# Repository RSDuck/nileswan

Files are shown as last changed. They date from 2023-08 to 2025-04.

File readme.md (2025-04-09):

# nileswan

An attempt at creating flash cartridge for Wonderswan.

Expect exciting things here.

## Building instructions

### Requirements

- [OSS CAD Suite](https://github.com/YosysHQ/oss-cad-suite-build) (FPGA core)
  - Requires a modified version of `icepack`, see below for more information
- [Wonderful Toolchain](https://wonderful.asie.pl/wiki/doku.php?id=getting_started) (IPL1, recovery, updater)
- CMake (MCU firmware)
- NASM (IPL0)
- Nim 2.0+ (FPGA core, IPL0)
- Ninja (MCU firmware)
- Python 3.x (SPI images, updater)
  - + `crc` library
- dd, dosfstools, mtools (emulator images)

#### icepack

For the FPGA to be ready in time, the bitstream needs to be loaded at the highest speed possible. I created a [PR](https://github.com/YosysHQ/icestorm/pull/332) for icepack which adds a setting to change this. Without it is not possible to compile the FPGA bitstream.

### Compiling

1. Make sure to fetch the Git submodules: `git submodule update --init --recursive`.
2. Run `make help` to read what build options are possible.
3. Run `make` (or `make ...`) to build the requested components.

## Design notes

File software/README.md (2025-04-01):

# software

Console-side software used by the nileswan's boot/manufacturing process.

## ipl0

The first stage bootloader; up to 512 bytes, stored in FPGA memory. Its goal is to:

- preserve initial boot state in console RAM for the second stage bootloader,
- choose the second stage bootloader to load (boot, safe),
- load the second stage bootloader from SPI flash to console RAM,
- jump to the second stage bootloader.

## ipl1

The second stage bootloader; up to ~15 kilobytes, stored in SPI flash. It contains
a few sub-variants:

### boot

This is the default second stage bootloader. Its goal is to:

- initialize the IPC memory layout,
- initialize the storage card inserted into the console,
- load a program (`/NILESWAN/MENU.WS`) to PSRAM,
- jump to PSRAM.

### safe

Its goal is to provide recovery options in case the user requests them by holding
the on-cartridge button at boot. This is still being worked on.

## libnile

Common library for nileswan functionality, developed in a separate repository.

## userland

Cartridge-layout programs using shared minimal user interface code.

### recovery

Larger recovery program which can optionally be launched through `ipl1/safe`.

### updater

This is the firmware updater program source code. It can be combined with a
manifest file to create an on-console flashable firmware upgrade.

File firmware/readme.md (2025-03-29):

# μController firmware

Firmware for the STM32L052K(6/8)Ux MCU. Its responsibilities include:

- USB communication (CDC, ...),
- real-time clock (time keeping, S-3511A emulation),
- backup EEPROM storage.

For RTC support/EEPROM storage, it is constantly powered by the backup battery, even when the console is powered off.

## Protocol

The MCU is connected on the same SPI bus as the SPI flash.

### Command mode

To initiate a transaction, send two bytes declaring the command ID (bits 0-6) and parameter (bits 7-15, values 0-511).

Each packet, except "Switch to mode", has a response. The response always consists of the length (two bytes) and the data.

#### 0x00 - Echo

Test command. The parameter is the number of bytes to echo, followed by the bytes to echo.

#### 0x01 - MCU: Switch to mode

The parameter is the ID of the mode of communication to use going forward:

- `00` - command mode
- `01` - EEPROM emulation mode
- `02` - RTC S-3511A emulation mode
- `FF` - standby mode (requires reset to respond to SPI again)

#### 0x02 - SPI: Set maximum frequency

The parameter is the maximum frequency to set:

- `00` - 384 KHz
- `01` - 6 MHz

The response is 1 on success, 0 on failure.

#### 0x03 - MCU: Get unique ID

The response is the unique ID of the chip.

#### 0x10 - EEPROM: Set emulation mode

Set the size of the emulated EEPROM:

- `00` - no EEPROM
- `01` - M93LC06
- `02` - M93LC46 compatible
- `03` - M93LC56 compatible
- `04` - M93LC66 compatible
- `05` - M93LC76 compatible
- `06` - M93LC86 compatible

The response is 1 on success, 0 on failure.

#### 0x11 - EEPROM: Erase all data

The response is empty.

#### 0x12 - EEPROM: Read data

The parameter is the number of words to read; the following word is the offset.

The response is the bytes read.

#### 0x13 - EEPROM: Write data

The parameter is the number of words to write; the following word is the offset, then the words to write.

The response is empty.

#### 0x14 - RTC: Send command

The parameter is the packet type to send to the emulated S-3511A, followed by the relevant bytes.

The response is the data returned by the emulated S-3511A.

#### 0x15 - EEPROM: Get emulation mode

The response is 1 byte - the EEPROM emulation mode.

#### 0x16 - MCU: Set save ID

The parameter is ignored; followed by four bytes of the save ID.

The response is 1 on success, 0 on failure.

#### 0x17 - MCU: Get save ID

The parameter is ignored.

The response is four bytes of the save ID.

#### 0x40 - USB: CDC: Read

The parameter is the maximum number of bytes to read. The value 0 is treated as 512 bytes.

The response is the data read from the CDC.

#### 0x41 - USB: CDC: Write

The parameter is the number of bytes to write. The value 0 is treated as 512 bytes.

The response is two bytes in size and is the number of bytes successfully written.

#### 0x42 - USB: HID: Write

The parameter is the length of the packet.

The data sent is two bytes - the result of a keypad scan.

The response is zero bytes in size.

#### 0x7F - Reserved

Reserved to distinguish 0xFF bytes from commands.

### EEPROM mode

The EEPROM mode operates by exchanging words via SPI. It emulates the M93LCx6 interface.

### RTC mode

The RTC mode operates by exchanging bytes via SPI. It emulates the S-3511A interface.

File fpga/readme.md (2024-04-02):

# FPGA

- `rtl`: "Gateware" for the iCE40 FPGA on the nileswan
- `ipl0`: the first boot stage running on the FPGA, thus it has to be embedded into bitstream

## IPL0

512-byte program stored as the initial value of one EBRAM block which is mapped at bank 500 and bank 511 to boot from it on Pocket Challange V2 or Wonderswan respectively.

## Building

```
make
```

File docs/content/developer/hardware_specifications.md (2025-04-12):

---
title: 'Hardware overview'
weight: 0
---

nileswan emulates the following hardware:

- Up to 16 MiB of ROM space
- Up to 512 KiB of RAM space, with battery back-up
- 2001 and 2003-compatible I/O ports, including port 0xCE
- Up to 2 KiB of EEPROM space (M93LC46, M93LC76 and M93LC86 compatible), with back-up
- S-3511A compatible real-time clock

In addition, nileswan provides the following native hardware facilities for user homebrew:

- Removable storage card, via SPI interface
- USB port for CDC serial transfers, via MCU and SPI interface
- 512 bytes of inter-process communication memory

## Limitations

Most of these limitations should not impact end users; however, documenting them may be of use to homebrew developers.

- 32 KiB SRAM is mapped as if it were 64 KiB SRAM - mirroring is emulated at the bank level, but not within a bank.
- RTC command timings are slightly slower than on real hardware. This is a compromise between accuracy and power consumption.
- EEPROM write and erase timings are not guaranteed to match real hardware. This may be improved in the future with firmware updates. Note that, in general, EEPROM write and erase timings are not guaranteed to be consistent across cartridges.
- Due to hardware limitations, the emulation of the MBM29DL400TC NOR flash chip used on certain cartridges is very limited. Writes are correctly passed through, but other commands, including erases, may be stubbed or unimplemented.
- The ability to set jumpers using GPIO pins is not yet implemented. This will be resolved in the future with a firmware update.
- No infrared transmitter or transceiver is present on the cartridge board.
- No sonar is connected to the cartridge board.
- If the 8-bit ROM access width is used, the native SPI area is not correctly mapped. This may be resolved in the future with a firmware update.

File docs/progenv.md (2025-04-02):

# Programming environment

## I/O port map

| Address|Width| Name | Description |
|---|-----|---|---|
| `0xE0` |  2  | SPI_CNT | SPI control register |
| `0xE2` |  1  | POW_CNT | Power control |
| `0xE3` |  1  | NILE_IRQ | Controls nileswan IRQ |
| `0xE4` |  2  | BANK_MASK  | Mask for bank index |
| `0xE6` |  1  | EMU_CNT  | Controls EEPROM size |

## I/O ports

### SPI

**`0xE0` - `SPI_CNT` (16 bit)**
| Bit(s) | Description |
|---|---|
|0-8|SPI transfer length in bytes minus one|
|9-10|Mode (0 = write, 1 = read, 2 = exchange, 3 = wait and read) |
|11|Transfer speed (0 = 24 MHz "high frequency clock", 1 = 384 kHz from cartbus)|
|12-13|Channel select/chip select (0=no device selected and output to TF channel, 1=select TF, 2=select flash, 3=select μC)|
|14|Memory mapped RX and TX buffer index (0-1)|
|15|Start/busy, when written (0=abort transfer, 1=start transfer), when read (0=idle, 1=transferring)|

* In read mode all output serial bits are 1. The incoming bits are stored in the RX buffer.
* In write mode bits from the TX buffer are output. The incoming serial bits are discarded.
* In exchange mode the TX buffer is output, while simultaneously the RX buffer is populated with incoming data.
* Wait and read mode behaves like read mode except bytes are only stored with the first byte received which is not 0xFF.

During transfer the data in the TX buffer currently not mapped into the address space is sent out. The received data is stored in the RX buffer currently not memory mapped. The transfer always starts from the beginning of the buffers.

All values besides the transfer abort are read only while a transfer is in progress.

Transfer aborting is not immediate for internal reasons and to allow the transfer to end cleanly on a byte boundary. After an abort is issued the busy bit will continue to be high until the abort is finally completed.

For EEPROM or RTC SPI communication to work the cartridge serial clock has to be selected.

### Power/system control

**`0xE2` - `POW_CNT` (8 bit)**
| Bit(s) | Description |
|---|---|
|0|Enable 24 MHz high frequency clock. (0=off, 1=on (default))|
|1|Enable TF power (0=off (default), 1=on)|
|2|Enable nileswan exclusive I/O registers (0=off, 1=on (default))|
|3|Enable Bandai 2001 exclusive I/O registers (0=off, 1=on (default))|
|4|Enable Bandai 2003 exclusive I/O registers (0=off, 1=on (default))|
|5|Pull μC BOOT0/μC busy high (0=no/μC may communicate via it, 1=yes)|
|6|Enable SRAM (0=off, 1=on (default))|
|7|μC reset line|

If `0xFD` is written to `POW_CNT` it will reset the entire register even if nileswan registers are disabled. This way the nileswan registers can be brought back after disabling them.

Disabling a range of I/O registers only changes the visibility. E.g. the upper banking bits of the Bandai 2003 mapper continue to apply even if the registers used to change them are not accessible anymore.

The μC reset line bit directly connects to the nRST pin of the microcontroller.

μC BOOT0 controls whether the microcontroller starts from bootloader ROM or programmable flash (see STM32 documentation). The line is shared with busy line for emulated EEPROM operations and is open drain idling at low.

If SRAM is enabled SRAM (banks 0-7) may be selected when accessing the RAM area.

** `0xE6` - `EMU_CNT`

| Bit(s) | Description |
|---|---|
|0-1|Emulated EEPROM size (0=128B, 1=1KB, 2=2KB, 3=no EEPROM connected (default))|
|2|Flash emulation enable (0=disabled (default), 1=enabled)|
|3-7|Unused/0|

See section on EEPROM for details on EEPROM size.

When flash emulation the FPGA will provide minimal emulation of the programming sequences of parallel NOR flash memory for PSRAM accesses.

### Interrupts

**`0xE3` - `NILE_IRQ` (8 bit)**
| Bit(s) | Description |
|---|---|
|0|Enable SPI IRQ generation|
|1|SPI IRQ status, when read (0 = no IRQ, 1 = IRQ), when written (0 = nothing, 1 = acknowledge IRQ)|
|2-7|Unused/0|

If SPI IRQ generation is enabled an IRQ will be generated whenever the the busy bit of `SPI_CNT` changes from 1 to 0. It is signalled and acknowledgeable via the SPI IRQ status bit.

### Banking

**`0xE4` - `BANK_MASK` (16 bit)**
| Bit(s) | Description |
|---|---|
|0-8|Mask to be applied to ROM bank index|
|9|Use mask for accesses in ROM0 area (0 = no, 1 = yes (default))|
|10|Use mask for accesses in ROM1 area (0 = no, 1 = yes (default))|
|11|Use mask for accesses in RAM area (0 = no, 1 = yes (default))|
|12-15|Mask to be applied to RAM bank index|

To allow booting from bootrom the masks are initialised with all bits set.

Bank mask is always applied to the extended ROM bank (starting from 0x40000).

## EEPROM

If Bandai 2001 registers are enabled in `POW_CNT`, the registers associated with EEPROM (`0xC4`-`0xC8`) are accessible and writeable. The FPGA emulates the entire EEPROM including keeping its content of up to 2 KB in internal RAM.

This is necessary as the interface does not provide an reliable way to tell when a read is done and thus typically software only relies on waiting for a fixed amount. The μC is unable to respond with such low latency.

EEPROMs of different sizes have small differences in command scheme and mask addresses to their respective size. `EMU_CNT` can be used to set the size of the emulated EEPROM. Alternatively `EMU_CNT` can be configured to emulate the absence of an EEPROM chip.

To store save data across power cycles write and erase commands are additionally output as-is via SPI to the μC. First the contents of `CART_SERIAL_COM` is output from the highest to lowest bit, for write commands `CART_SERIAL_DATA` is output from highest to lowest bit too.

## RTC

Whenever Bandai 2003 registers are enabled via `POW_CNT` RTC registers can be accessed (`0xCA` and `0xCB`). It performs like a real Bandai 2003 and provides a serial interfaces specifically made for the S-3511A RTC chip. It is connected to the μC which emulates the S-3511A.

## Memory bank layout

### ROM (ROM0, ROM1, ROML)

| Bank(s) | Description |
|---|---|
|  0-127  | First PSRAM (8 MB) |
| 128-255 | Second PSRAM (8 MB, optional) |
| 256-499 | Unused (open bus) |
| 500 | Bootrom mirror (Pocket Challange V2 boot location) |
| 501-509 | Unused (open bus) |
| 510 | SPI RX buffer (read only, 512 bytes mirrored) |
| 511 | Bootrom (WonderSwan boot location) |

The PSRAM banks are writable by using the self flash mode (port 0xCE), which maps ROM at the point in the address space at which RAM usually sits (`0x10000`-`0x1FFFF`).

Note that while it is technically possible to read the SPI RX buffer and bootrom in the RAM bank, the values read will be incorrect - the RAM bank only supports byte accesses, while these banks only support 16-bit wide word accesses.

### RAM

|Bank(s)| Description |
|---|---|
| 0-7 | SRAM (512 KB) |
| 8-13  | Unused (open bus) |
| 14 | IPC buffer (512 bytes mirrored) |
| 15 | SPI TX buffer (write only, 512 bytes mirrored) |

## Memory banks

### RAM bank 14: IPC

This area is used for inter-process communication by software that targets the nileswan.

|Address| Size | Description |
|---|---|---|
| 0x000 | 2 | 0xAA55 if area valid |
| 0x002 | 1 | Cold boot entrypoint |
| 0x003 | 1 | TF card status |
| 0x004 | 4 | Reserved |
| 0x008 | 24 | Cold boot register backup: AX, BX, CX, DX, SP, BP, SI, DI, DS, ES, SS, FLAGS |
| 0x020 |  184 | Cold boot I/O port backup: 0x00 ~ 0xB7 |
| 0x0D8 | 8 | Reserved |
| 0x0E0 |  288 | Free to use for programs |

#### Cold boot entrypoint

* 0 - FFFF:0000 (standard - WS/WSC)
* 1 - 4000:0000 (alternate #1)
* 2 - 4000:0010 (alternate #2 - PCv2)

#### TF card status

    7  bit  0
    ---- ----
    bttt tttt
    |||| ||||
    |+++-++++- TF card type
    |          - 0: no card
    |          - 1: MMCv3
    |          - 2: MMCv4 (> 2 GB)
    |          - 3: TF
    |          - 4: TF (> 2 GB)
    +--------- Card uses block instead of byte addressing

### ROM bank 510, RAM bank 15: SPI buffers

The SPI RX and TX buffer are double-buffered. This means one buffer is visible to the console, while the other is used by the FPGA for facilitating an ongoing SPI transfer. These buffers can be swapped using `SPI_CNT`.

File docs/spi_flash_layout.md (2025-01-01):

# SPI flash layout

## Write-protected area

|  Start | End | Description  |
|---|---|---|
| 0x000000 | 0x007FFF | FPGA core 0 (factory) + header |
| 0x008000 | 0x00BFFF | IPL1 (factory) |
| 0x00C000 | 0x00FFFF | IPL1 (recovery) |
| 0x010000 | 0x03FFFF | Recovery software (factory) |

## Write-unprotected area

|  Start | End | Description  |
|---|---|---|
| 0x040000 | 0x043FFF | IPL1 (current) |
| 0x044000 | 0x04FFFF | Reserved |
| 0x050000 | 0x07FFFF | Recovery software (current) |
| 0x080000 | 0x087FFF | FPGA core 1 |
| 0x088000 | 0x08FFFF | FPGA core 2 |
| 0x090000 | 0x097FFF | FPGA core 3 |
| 0x098000 | 0x09FFFF | FPGA core 4 |
| 0x0A0000 | 0x1FFFFF | Unused (future expansion) |

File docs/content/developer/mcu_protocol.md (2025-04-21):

---
title: 'MCU firmware protocol'
weight: 50
---

This page documents protocols used to communicate with the on-board STM32 MCU via SPI.

## Bootloader protocol

This is the default mode after resetting with BOOT0 pulled high.

For details on this protocol, please refer to the ST Application note AN4286.

## Native mode

This is the default mode after resetting with BOOT0 pulled low.

To initiate a transaction, send a 16-bit little endian value (two bytes) declaring the command ID (in bits 0-6) and parameter (bits 7-15, values 0-511).

Every packet except "Switch to mode" has a response. The response always consists of the length (two bytes) and the data.

### 0x00 - Echo

Test command. The parameter is the number of bytes to echo, followed by the bytes to echo.

### 0x01 - MCU: Switch to mode

The parameter is the ID of the mode of communication to use going forward:

- `0x00` - command mode
- `0x01` - EEPROM emulation mode
- `0x02` - RTC S-3511A emulation mode
- `0x03` - CDC output mode (transferred SPI bytes are output via USB CDC)
- `0xFF` - standby mode (requires reset to respond to SPI again)

### 0x02 - SPI: Set maximum frequency

The parameter is the frequency that SPI should be adjusted to listen to:

- `0x00` - 384 KHz
- `0x01` - 6 MHz
- `0x02` - 24 MHz

The response is 1 on success, 0 on failure.

The on-flash code most likely is not fast enough to deal with the higher-speed modes; this requires further research.

### 0x03 - MCU: Get unique ID

The response is the unique ID of the chip.

### 0x10 - EEPROM: Set emulation mode

Set the size of the emulated EEPROM:

- `0x00` - no EEPROM
- `0x01` - M93LC06
- `0x02` - M93LC46 compatible
- `0x03` - M93LC56 compatible
- `0x04` - M93LC66 compatible
- `0x05` - M93LC76 compatible
- `0x06` - M93LC86 compatible

The response is 1 on success, 0 on failure.

### 0x11 - EEPROM: Erase all data

The response is empty.

### 0x12 - EEPROM: Read data

The parameter is the number of words to read; the following word is the offset.

The response is the bytes read.

### 0x13 - EEPROM: Write data

The parameter is the number of words to write; the following word is the offset, then the words to write.

The response is empty.

### 0x14 - RTC: Send command

The parameter is the packet type to send to the emulated S-3511A, followed by the relevant bytes.

The response is the data returned by the emulated S-3511A.

### 0x15 - EEPROM: Get emulation mode

The response is 1 byte - the EEPROM emulation mode.

### 0x16 - MCU: Set save ID

The parameter specifies the save ID location:

- `0x01`: SRAM2 (if the save ID depends on data stored in SRAM2, such as EEPROM),
- `0x02`: RTC backup domain (if it doesn't),
- `0x03`: both.

The command is followed by four bytes of the save ID.

The save ID `0xFFFFFFFF` is reserved and means "no save is stored".

The response is 1 on success, 0 on failure.

### 0x17 - MCU: Get save ID

The parameter specifies the save ID location.

The response is four bytes of the save ID.

### 0x40 - USB: CDC: Read

The parameter is the maximum number of bytes to read. The value 0 is treated as 512 bytes.

The response is the data read from the CDC.

### 0x41 - USB: CDC: Write

The parameter is the number of bytes to write. The value 0 is treated as 512 bytes.

The response is two bytes in size and is the number of bytes successfully written.

### 0x42 - USB: HID: Write

The parameter is the length of the packet.

The data sent is two bytes - the result of a keypad scan.

The response is zero bytes in size.

### 0x7F - Reserved

Reserved to distinguish 0xFF bytes from commands.

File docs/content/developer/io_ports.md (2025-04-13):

---
title: 'I/O port map'
weight: 10
---
| Address |Width| Name | Description |
|---|-----|---|---|
| `0xE0` |  2  | SPI_CNT | SPI control register |
| `0xE2` |  1  | POW_CNT | Power control |
| `0xE3` |  1  | EMU_CNT  | Behavior control (EEPROM, flash emulation, ...) |
| `0xE4` |  2  | BANK_MASK  | Mask for bank index |
| `0xE6` (read)  |  1  | BOARD_REVISION | Board revision |
| `0xE6` (write) |  1  | WARMBOOT_CNT | Trigger FPGA warmboot |
| `0xE8` |  1  | IRQ_ENABLE | Cartridge IRQ enable |
| `0xE9` |  1  | IRQ_STATUS | Cartridge IRQ status |

## SPI interface

**`0xE0` - `SPI_CNT` (16-bit, read/write)**
| Bit(s) | Description |
|---|---|
|0-8|SPI transfer length in bytes minus one|
|9-10|Mode (0 = write, 1 = read, 2 = exchange, 3 = wait and read) |
|11|Transfer speed (0 = 24 MHz "high frequency clock", 1 = cartridge bus clock, usually 384 KHz) |
|12-13|Channel select/chip select (0 = no device selected and output to TF channel, 1 = select TF, 2 = select flash, 3 = select μC)|
|14|Memory mapped RX and TX buffer index (0-1)|
|15|Start/busy, when written (0 = abort transfer, 1 = start transfer), when read (0 = idle, 1 = transferring)|

* In read mode all output serial bits are 1. The incoming bits are stored in the RX buffer.
* In write mode bits from the TX buffer are output. The incoming serial bits are discarded.
* In exchange mode the TX buffer is output, while simultaneously the RX buffer is populated with incoming data.
* Wait and read mode behaves like read mode except bytes are only stored with the first byte received which is not 0xFF.

During transfer the data in the TX buffer currently not mapped into the address space is sent out. The received data is stored in the RX buffer currently not memory mapped. The transfer always starts from the beginning of the buffers.

All values besides the transfer abort are read only while a transfer is in progress.

Transfer aborting is not immediate for internal reasons and to allow the transfer to end cleanly on a byte boundary. After an abort is issued the busy bit will continue to be high until the abort is finally completed.

For EEPROM or RTC SPI communication to work, the cartridge serial clock has to be selected.

## Cartridge control

**`0xE2` - `POW_CNT` (8-bit, read/write)**

| Bit(s) | Description |
|---|---|
|0|Enable 24 MHz high frequency clock. (0=off, 1=on (default))|
|1|Enable TF power (0=off (default), 1=on)|
|2|Enable nileswan I/O registers (0=off, 1=on (default))|
|3|Enable 2001 mapper-specific I/O registers (0=off, 1=on (default))|
|4|Enable 2003 mapper-specific I/O registers (0=off, 1=on (default))|
|5|Pull μC BOOT0/μC busy high (0=no/μC may communicate via it, 1=yes)|
|6|Enable SRAM (0=off, 1=on (default))|
|7|μC reset line|

If `0xDD` is written to `POW_CNT` it will reset the entire register even if nileswan registers are disabled. This allows unlocking the nileswan I/O ports after they have been disabled.

Disabling a range of I/O registers only changes their visibility; it does not disable their functiion. E.g. the upper banking bits of the 2003 mapper continue to apply even if the registers used to change them are not accessible anymore.

The μC reset line bit is connected directly to the nRST pin of the microcontroller.

μC BOOT0 controls whether the microcontroller starts from bootloader ROM or programmable flash (see STM32 documentation). The line is shared with busy line for emulated EEPROM operations and is open drain idling at low.

If SRAM is enabled SRAM (banks 0-7) may be selected when accessing the RAM area.

**`0xE3` - `EMU_CNT` (8-bit, read/write)**

| Bit(s) | Description |
|---|---|
|0-1|Emulated EEPROM size (0=128B, 1=1KB, 2=2KB, 3=no EEPROM connected (default))|
|2|Flash emulation enable (0=disabled (default), 1=enabled)|
|3|Emulated ROM bus width (0=16-bit (default), 1=8-bit)|
|4-7|Unused/0|

See section on EEPROM for details on EEPROM size.

When flash emulation the FPGA will provide minimal emulation of the programming sequences of parallel NOR flash memory for PSRAM accesses.

**`0xE6` - `BOARD_REVISION` (8-bit, read)**

| Bit(s) | Description |
|---|---|
|0-7|Board revision|

Used for distinguishing boards during firmware updates.

|Value | Description |
|---|---|
| 0x00 | rev. 6 |
| 0x01 | rev. 7 |

**`0xE6` - `WARMBOOT_CNT` (8-bit, write)**

| Bit(s) | Description |
|---|---|
|0-1|Warmboot image to boot (0-3)|

After writing the FPGA will load one of four FPGA cores from SPI flash depending on the value written. The core image locations are documented in the SPI flash layout.

It may only be written while not running code from the cartridge. After writing, a wait of approximately 20 milliseconds is necessary until the cartridge responds again.

{{< hint type=important >}}
If your FPGA core image does not [enable](https://github.com/YosysHQ/icestorm/pull/332) a faster frequency range,
the wait may need to be as high as 53 milliseconds.
{{< /hint >}}

## Interrupt handling

**`0xE8` - `IRQ_ENABLE` (8-bit, read/write)**

| Bit(s) | Description |
|---|---|
|0|Pass MCU IRQ line|
|1-7|Unused/0|

**`0xE9` - `IRQ_STATUS` (8-bit, read/write)**

| Bit(s) | Description |
|---|---|
|0|MCU IRQ line|
|1-7|Unused/0|

## Banking

**`0xE4` - `BANK_MASK` (16-bit, read/write)**
| Bit(s) | Description |
|---|---|
|0-8|Mask to be applied to ROM bank index|
|9|Use mask for accesses in ROM0 area (0 = no, 1 = yes (default))|
|10|Use mask for accesses in ROM1 area (0 = no, 1 = yes (default))|
|11|Use mask for accesses in RAM area (0 = no, 1 = yes (default))|
|12-15|Mask to be applied to RAM bank index|

To allow booting from bootrom the masks are initialised with all bits set.

Bank mask is always applied to the extended ROM bank (starting from 0x40000).

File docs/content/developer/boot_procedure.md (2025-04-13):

---
title: 'Boot procedure'
weight: 30
---

nileswan uses a two-stage boot loader.

{{< mermaid class="text-center" >}}
flowchart LR
    C[Console IPL] -->|FPGA core| A0[IPL0]
    A0 -->|SPI flash| A1[IPL1 /boot/]
    A0 -->|SPI flash - X3 + B held| A3[IPL1 /recovery/]
    A3 -->|SPI flash| A4[Recovery]
    A1 -->|TF card| A2[MENU.WS]
{{< /mermaid >}}

## IPL0

The first-stage boot loader is 512 bytes in size. It is stored in the factory FPGA core.

Its goal is to:

- reset the nileswan hardware,
- store the console register and I/O port state in console internal RAM,
- load IPL1 from SPI flash to console internal RAM.

## IPL1

The second-stage boot loader is up to `0x37C0` (14272) bytes in size. It is stored in the SPI flash. It uses a special 16-byte header:

|Offset|Size| Description |
|---|----|---|
| 0x0  | 2  | Load address (typically 0x0040) |
| 0x2  | 2  | Number of 512-byte sectors to load from SPI flash |
| 0x4  | 12 | Reserved |

It has two variants:

### IPL1 (boot)

The "boot" variant is bundled with the storage card driver. Its goal is to:

- validate the IPC memory area and populate it if necessary,
- switch to the update-provided FPGA core (unless the factory version of IPL1 is forced by holding the on-cartridge button),
- load `/NILESWAN/MENU.WS` from the storage card.

### IPL1 (recovery)

The "recovery" variant instead reserves space for testing functionality, such as:

- performing a test of onboard PSRAM and SRAM memory,
- allowing to load a dedicated recovery program from SPI flash.

## Recovery

The recovery program is up to 256 KiB in size (or 192 KiB for the factory-provided version). It is formatted like a standard WS cartridge image.

It is better documented as part of the [User Guide](/user/troubleshooting/recovery).

## MENU.WS

The menu program is loaded to the final banks of PSRAM (bank `0xFF` downwards). It is formatted like a standard WS cartridge image.

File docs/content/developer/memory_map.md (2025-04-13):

---
title: 'Memory bank map'
weight: 15
---

### ROM (ROM0, ROM1, ROML)

| Bank(s) | Description |
|---|---|
|  0-127  | First PSRAM (8 MB) |
| 128-255 | Second PSRAM (8 MB, optional) |
| 256-499 | Unused (open bus) |
| 500 | Bootrom mirror (pin strap/PCv2 boot location) |
| 501-509 | Unused (open bus) |
| 510 | SPI RX buffer (read only, 512 bytes mirrored) |
| 511 | Bootrom (WS/WSC boot location) |

The PSRAM banks are writable by using the self flash mode (port 0xCE), which maps ROM at the point in the address space at which RAM usually sits (`0x10000`-`0x1FFFF`).

Note that while it is technically possible to read the SPI RX buffer and bootrom in the RAM bank, the values read will be incorrect - the RAM bank only supports byte accesses, while these banks only support 16-bit wide word accesses.

## RAM

|Bank(s)| Description |
|---|---|
| 0-7 | SRAM (512 KB) |
| 8-13  | Unused (open bus) |
| 14 | IPC buffer (512 bytes mirrored) |
| 15 | SPI TX buffer (write only, 512 bytes mirrored) |

## IPC buffer

This area is used for inter-process communication by software that targets the nileswan.

|Address| Size | Description |
|---|---|---|
| 0x000 | 2 | 0xAA55 if area valid |
| 0x002 | 1 | Cold boot entrypoint |
| 0x003 | 1 | TF card status |
| 0x004 | 4 | Reserved |
| 0x008 | 24 | Cold boot register backup: AX, BX, CX, DX, SP, BP, SI, DI, DS, ES, SS, FLAGS |
| 0x020 |  184 | Cold boot I/O port backup: 0x00 ~ 0xB7 |
| 0x0D8 | 8 | Reserved |
| 0x0E0 |  288 | Free to use for programs |

### Cold boot entrypoint

* 0 - FFFF:0000 (standard - WS/WSC)
* 1 - 4000:0000 (alternate #1)
* 2 - 4000:0010 (alternate #2 - PCv2)

### TF card status

    7  bit  0
    ---- ----
    bttt tttt
    |||| ||||
    |+++-++++- TF card type
    |          - 0x00: no card
    |          - 0x01: MMC (older)
    |          - 0x02: MMC (newer)
    |          - 0x04: TF (older)
    |          - 0x08: TF (newer)
    +--------- Card uses block instead of byte addressing

When disabling removable storage card power, this byte should also be set to `0`; otherwise, filesystem drivers may fail to work correctly.

## SPI RX/TX buffer

The SPI RX and TX buffer are double-buffered. This means one buffer is visible to the console, while the other is used by the FPGA for facilitating an ongoing SPI transfer. These buffers can be swapped using `SPI_CNT`.

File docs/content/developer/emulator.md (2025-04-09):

---
title: 'Device emulator'
weight: 5
---

In addition to physical hardware, a device emulator can be used for testing nileswan software. The current device
emulator is a fork of the [Mednafen](https://mednafen.github.io/) emulator; however, it is maintained by us, so
please do not ask Mednafen's developers questions about it.

The main advantage of the device emulator is that it allows much more rapid test cycles on a development computer. In addition,
stepping and breakpoint functionality is provided for debugging. The main disadvantage is that the emulator only implements
a limited subset of both the console and the cartridge's functionality.

## Installation

1. [Download](https://github.com/49bitcat/nileswan-medem/releases) or [compile](https://github.com/49bitcat/nileswan-medem) the device emulator.
2. Prepare the emulator files. This can be done by either:
    - [downloading](https://github.com/49bitcat/nileswan/releases) a ready-made build of the package,
    - [compiling](https://github.com/49bitcat/nileswan) the package from source by using the `make dist-emu` command; in this case, the package will be placed in the `out/emulator` directory.
3. Place the emulator files in a directory of your choosing. You should have the following files:
    - `nileswan.ipl0` - a build of the IPL0 (first-stage loader),
    - `nileswan.spi` - a replica of the SPI flash image,
    - `nileswan.img` - a pre-formatted FAT32 image, emulating the removable storage card.
4. Use a tool of choice (for example, `mount -o loop nileswan.img ...` on Linux) to mount the pre-formatted FAT32 image and edit its contents.
5. Run the emulator: `nileswan-medem nileswan.ipl0`.

## Supported features

| Feature | Supported? | Notes |
|---|---|---|
| SPI interface | Yes | |
| Power control | Yes | |
| SPI removable storage | Partial | Some commands only, <= 2 GiB only |
| SPI flash | Partial | Some commands only |
| MCU bootloader | Stubbed | MCU flash not stored |
| MCU native | Partial | Some commands only |
| MCU EEPROM | No | |
| MCU RTC | Stubbed | |
| MCU CDC transfer | Yes | Use `wswan.excomm` config option |
| IPC area | Yes | |
| Flash FSM | Yes | |

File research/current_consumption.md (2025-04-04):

# Power draw

As the default mean of powering a Wonderswan is a single AA battery keeping an eye on the power consumption of the cartridge is very important. This is especially true for the original Wonderswan model, where the boost converter is said to be less capable than the ones in the later two models.

## Power draw of a cartridge

Some figures on the power draw of a cartridge:

| Setup | Battery draw (in mA at 1.5 V) |
|---|---|
|Chocobo Dungeon (real cartridge), title screen|36|
|Crazy Climber (real cartridge), intro animation|42|
|Crazy Climber (externally powered FPGA board), intro animation|36|

All measurements were made on a monochrome Wonderswan.

From this limited data we can conclude that a ROM only cartridge such as Crazy Climber draws a current of about 6 mA.

## microSD cards

Even if we try to hold the power consumption of the cartridge as low as possible, if we want to use microSD cards as a storage medium, we need to deal with their power consumption. Fortunately once the ROM is loaded into PSRAM this is not an concern anymore, assuming the microSD card has a low enough sleep current.

To keep concurrent power draw low, it is probably the smartest to not select the SD card and PSRAM at the same time. Putting the processor to sleep and buffering into the FPGA's integrated SRAM might be the way to go.

Based on various sources, at a relatively low frequency of a few MHz, a microSD card can still be expected to draw on average between 20-30 mA at 3.3 V, with very current spikes from time to time.

## Monochrome Wonderswan: stress tests

An additional load was added to the 3.3 V line of a monochrome Wonderswan. Initially white LEDs in series with 75 Ohm resistors were used. After I ran out of those, white LEDs in series with 180 Ohm resistors were used. After running dry of LEDs, 180 Ohm resistors were put directly between 3.3 V and GND.

For the tests the intro of Gunpey was running.

| Voltage (in V) | Additional current (in mA) |
|---|---|
|3.256|0|
|3.242|27|
|3.226|42.8|
|3.2| 56-57|
|3.16|72|
|3.11|84|
|2.99|94|

Concluding from this, even on a monochrome Wonderswan it should be possible to use a microSD card, assuming there are no other additional consumers of power such as backlighted displays.

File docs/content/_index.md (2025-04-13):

---
title: 'nileswan documentation'
---

Welcome to the documentation for nileswan, a homebrew-friendly flash cartridge for WS/WSC/SC/PCv2 consoles.

If you're an user, check out the [Quickstart](user/quickstart) to start your journey.

If you'd like to test software for nileswan, but don't have a physical cartridge, you can make use of the [Device emulator](developer/emulator).

If you're a developer writing homebrew or library code for nileswan, please check out the developer guide in its entirety. The guide contains both implementation tips and reference documentation.

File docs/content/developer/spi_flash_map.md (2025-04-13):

---
title: 'SPI flash layout'
weight: 40
---

## Write-protected area

This area should be typically write-protected when running software.

|  Start | End | Description  |
|---|---|---|
| 0x000000 | 0x007FFF | FPGA bringup/factory core + header |
| 0x008000 | 0x00BFFF | IPL1 (factory) |
| 0x00C000 | 0x00FFFF | IPL1 (recovery) |
| 0x010000 | 0x03FFFF | Recovery software (factory) |

## Non-write-protected area

|  Start | End | Description  |
|---|---|---|
| 0x040000 | 0x043FFF | IPL1 (updated) |
| 0x044000 | 0x04FFFF | Reserved |
| 0x050000 | 0x07FFFF | Recovery software (updated) |
| 0x080000 | 0x087FFF | FPGA core 0 |
| 0x088000 | 0x08FFFF | FPGA core 1 |
| 0x090000 | 0x097FFF | FPGA core 2 |
| 0x098000 | 0x09FFFF | FPGA core 3 |
| 0x0A0000 | 0x1FFFFF | Unused (future expansion) |

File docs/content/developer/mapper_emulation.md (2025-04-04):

---
title: 'Mapper emulation'
weight: 20
---

## EEPROM

If 2001 mapper registers are enabled in `POW_CNT`, the registers associated with EEPROM (`0xC4`-`0xC8`) are accessible and writeable. The FPGA emulates the entire EEPROM including keeping its content of up to 2 KB in internal RAM.

This is necessary as the interface does not provide an reliable way to tell when a read is done and thus typically software only relies on waiting for a fixed amount. The μC is unable to respond with such low latency.

EEPROMs of different sizes have small differences in command scheme and mask addresses to their respective size. `EMU_CNT` can be used to set the size of the emulated EEPROM. Alternatively `EMU_CNT` can be configured to emulate the absence of an EEPROM chip.

To store save data across power cycles write and erase commands are additionally output as-is via SPI to the μC. First the contents of `CART_SERIAL_COM` is output from the highest to lowest bit, for write commands `CART_SERIAL_DATA` is output from highest to lowest bit too.

## RTC

Whenever 2003 mapper registers are enabled via `POW_CNT` RTC registers can be accessed (`0xCA` and `0xCB`). It performs like a real 2003 mapper and provides a serial interfaces specifically made for the S-3511A RTC chip. It is connected to the μC which emulates the S-3511A.

## Flash

The PSRAM banks are writable by using the self flash mode (port 0xCE), which maps PSRAM at the point in the address space at which RAM usually sits (`0x10000`-`0x1FFFF`).

Normally, this is accessible as regular RAM; the flash emulation mode can be enabled to inhibit writes which are not a result of valid flash write commands.

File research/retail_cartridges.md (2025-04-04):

# Retail cartridges

## Construction of WS cartridges

Refer to http://perfectkiosk.net/stsws.html#cart for a pinout of the Wonderswan cartridge bus. Frutratingly WSman has a few pins in its pinout swapped.

Commercially sold Wonderswan games usually contained these components:

* A 16-bit wide ROM chip containing the main game data
* The Bandai chip (either Bandai 2001 or Bandai 2003)

Also optionally either:

* 8-bit wide SRAM for save data, a battery and the GIZA chip
* EEPROM to store save data

Additionally some games contain a real time clock.

Both the ROM and SRAM are connected to the lower 16 address lines and all 16 data lines (ROM), the lower 8 data lines (SRAM), as well as the `/OE` and `/WE` signal.

The Bandai chip is connected to `A0`-`A3`, `A16`-`A19`, `D0`-`D7`, as well as all the control signals. It also serves as a connection serial peripherals like EEPROM or an RTC.

For a schematic of such a cartridge see up-n-atom's [WonderWitch clone](https://github.com/up-n-atom/WonderWitch). Note that the WonderWitch uses a parallel flash memory in place of the ROM chip as it needs to be rewritable.

## Memory access

Both the ROM and the SRAM chip use a standard asynchronous memory interface.

In this trace the CPU access memory repeated. It sets up the address while `/OE` is high (marked in green) and then sets it low, which (marked in pink) is when the Bandai chip will select the right chip, which will then provide the data.

For every memory access the Bandai chip will use the upper address bits (`A16`-`A19`) to select either the ROM or SRAM and provide the upper address bits (beyond the low 16-bits) based on its internal registers which can be set using I/O accesses.

It is presumed that the CPU latches the data to be read on the rising edge of `/OE`.

The byte at the lower address (even) is deliverd on `D0`-`D7` while byte at the upper address (odd) is delivered on `D8`-`D15`.

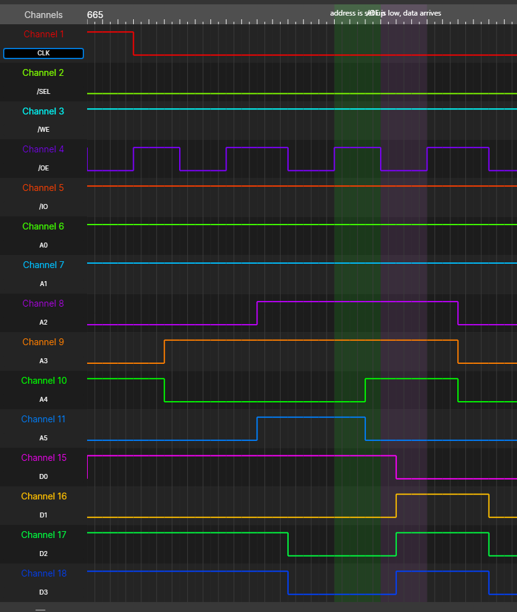
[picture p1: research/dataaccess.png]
Logic analyzer trace of a memory access


While the address seems to be applied already before `/WE` or `/OE` are pulled low, the data lines are only set during the falling edge (only confirmed for I/O writes).

So when not using a second clock (which would allow an arbitrary delay), it is probably the best to latch the write value on the rising edge of `/WE`.

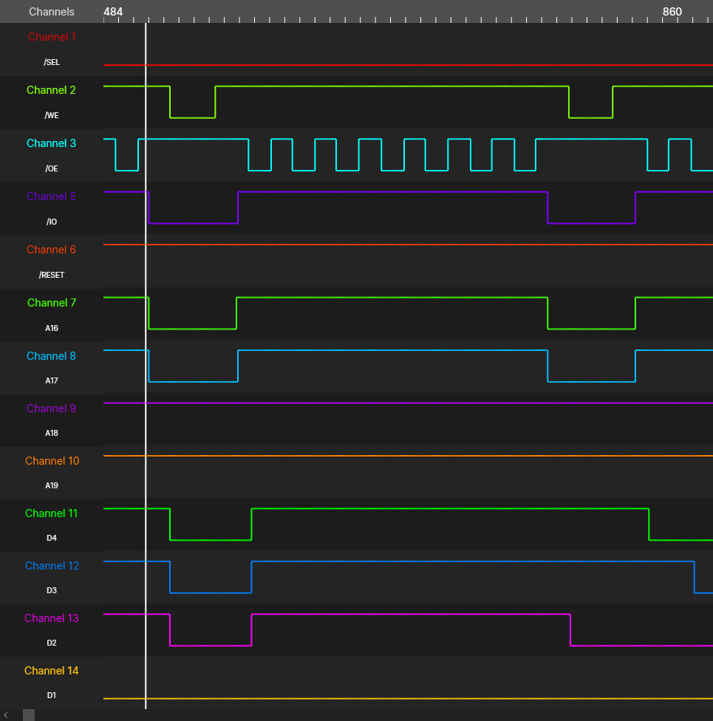
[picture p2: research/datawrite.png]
Logic analyzer trace of an I/O write


## I/O

Cartridge I/O registers are handled by the Bandai chip. They are made like regular memory accesses, except that the `/IO` signal is low during the regular `/OE` or `/WE` is. See again http://perfectkiosk.net/stsws.html#cart for more information.

I/O accesses are 8-bit wide (using `D0`-`D7`) with an 8-bit address. Since the Bandai chip is not connected to the full address bus, the upper four address bits are output on `A16`-`A19`.

## ROM width and self flashing

While SRAM accesses are always 8-bit wide, ROM can be configured to be either [8 or 16-bit wide](http://perfectkiosk.net/stsws.html#hardware_architecture). The 8-bit mode was reportedly never used by any commercial software.

For 16-bit ROMs the address line (`A0`) is not connected to the ROM chip. The SoC seems to rely on this force aligning memory accesses, because it sometimes issues reads with it set, while expecting the word with it ignored.

For rewritable cartridges whether using parallel flash memory like Wonderwitch or PSRAM like the nileswan it is desirable to write to the ROM with software running on the Wonderswan. When doing this two hurdles are encountered:

The first is that the SoC blocks writes to ROM from even going to the bus. This problem is solved by Bandai 2003 which gains the ability to set which memory (SRAM or ROM) is selected when accessing the SRAM area (0x10000-0x1FFFF) via the self flash register.

The second is the aforementioned limitation of the SRAM area which only allows 8-bit access size, while ROMs are usually 16-bit wide (which is advantagous due to bigger transfer size). Bandai 2003 again solves this in combination with special NOR flash memory which has a pin to decide whether a memory access is done width 8 or 16-bit width. When the Bandai 2003 is in self flash mode and SRAM is accessed it asserts the `/BYTE` signal of the flash memory. The least significant address bit `A0` is transfered from Bandai 2003 to `D15` of the flash memory which serves its secondary function as `A0` here. As only `D0`-`D7` carry data there is no conflict.

## Reset signal

After power up a monochrome Wonderswan `/RESET` stays low for about 18 ms.

Pulling it low again with an open drain I/O leads to a current of 1 mA on a monochrome Wonderswan and 4.9 mA on a color Wonderswan.

The reason, this can be important, is, that some FPGAs or microcontrollers need longer to initialise. Pulling the reset signal low again once they are done might be a viable option for them.

## Unlocking

Shortly after `/RESET` goes high again a handshake between the SoC (CPU) and the Bandai chip is performed. If it is not sucessful, the bootrom will refuse to load the game and not even show the Bandai logo.

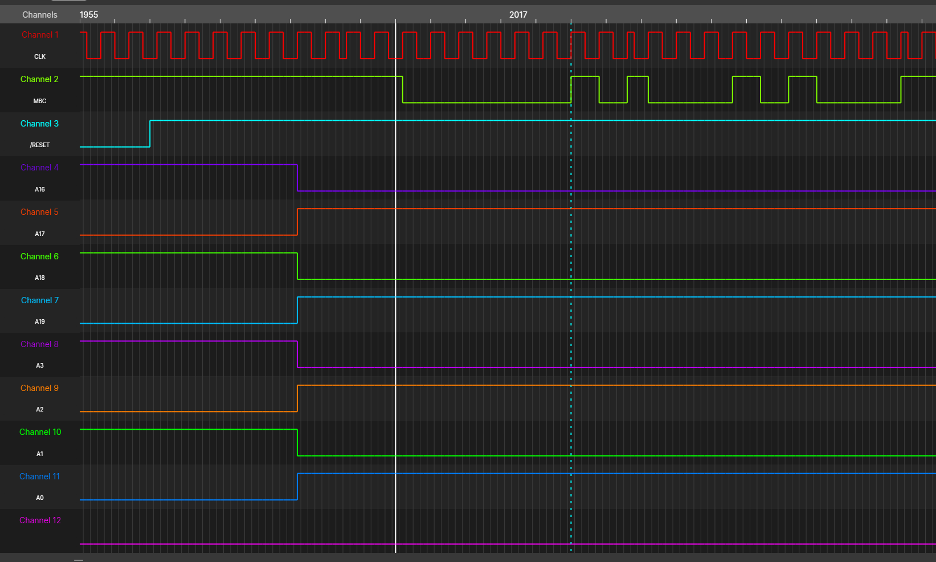
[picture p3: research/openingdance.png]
Logic analyzer trace of the unlock sequence


The opening sequence is synchronous to the serial clock signal. It begins after the the rising edge of the clock when `A0`-`A3` become 0x5 and and `A16`-`A19` become 0xA. On each subsequent rising edge a bit will be output via `MBC`. The sequence is (lowest bit output first) 0b1000101000101000000111. Afterwards `MBC` stays high indefinitely and is not used anymore until the system is reset.

It seems like there is some allowed variance in the number of cycles before the first low MBC value. Though how it is depicted in the trace (where it is output during the fourth rising edge after the rising edge with the address change) is how official Bandai chips seem to behave.

## Serial clock

The positive edge of the serial clock seems to always coincide with the positive edge of bus control signals `/OE` or `/WE`. This makes it easy to latch on either signals without having to fear timing violations.

## Speed requirements

Generally speaking the `/OE` or `/WE` signal seem to go low and high again with a frequency of about 3 MHz which is probably derived from the 12.288MHz system clock. This leaves half the period, so about 162 ns to handle one memory access.

## Power consumption

See [current consumption](current_consumption.md) for my experiments regarding this.

## Mechanical details

|Distance|Length (in mm)|
|---|---|
|Distance pad to pad|1.25|
|Left edge to first pad|0.7|
|Last pad to right edge|0.95|
|Bottom edge to longer pads (GND, Vcc)|0.5|
|Bottom edge to shorter pads|1|

TODO: make a proper mechanical drawing

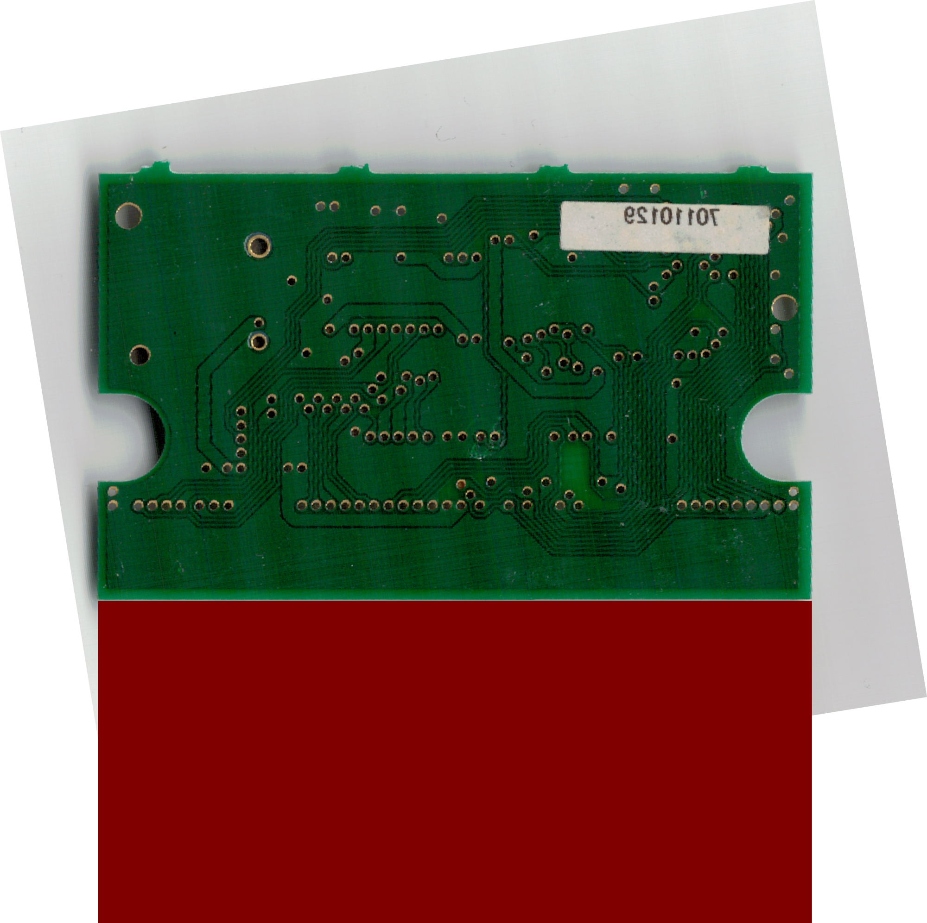
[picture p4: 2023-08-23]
research/cartridge_scan_back.png

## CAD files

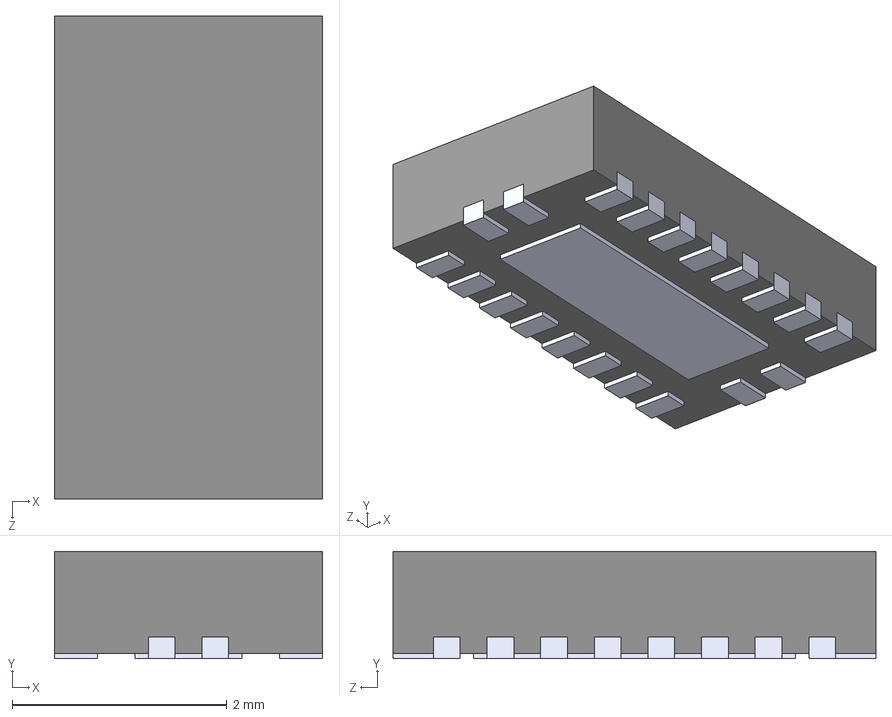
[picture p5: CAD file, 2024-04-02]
pcb/snapeda/models/74LVC245ABQ.step
2.50 x 1.00 x 4.50 mm

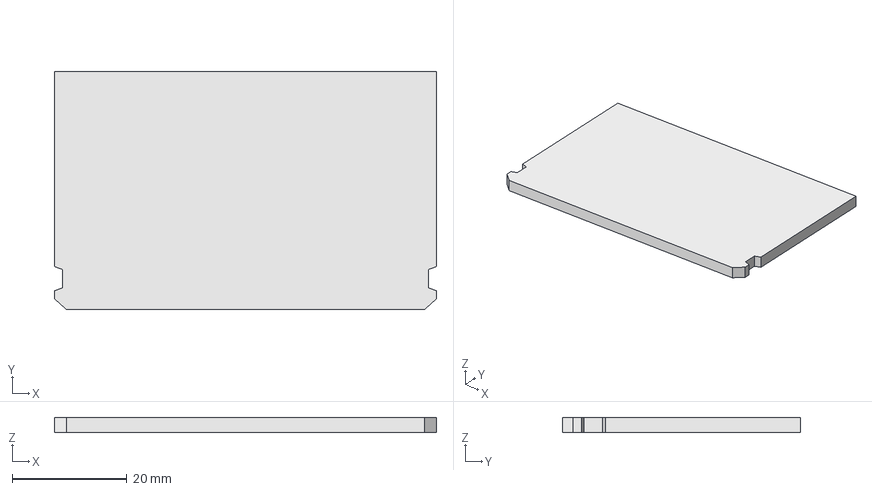
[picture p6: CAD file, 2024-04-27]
shell/shell.FCStd
66.5 x 41.5 x 2.60 mm

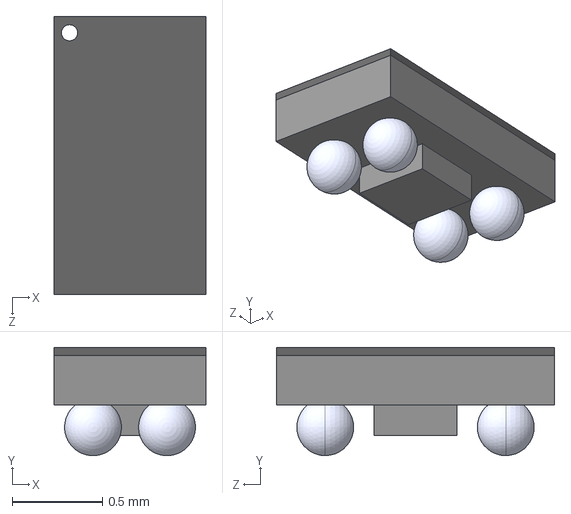
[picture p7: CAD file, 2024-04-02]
pcb/snapeda/models/SIT8021AI-J4-XXS-24.000000E.step
0.84 x 0.6 x 1.54 mm

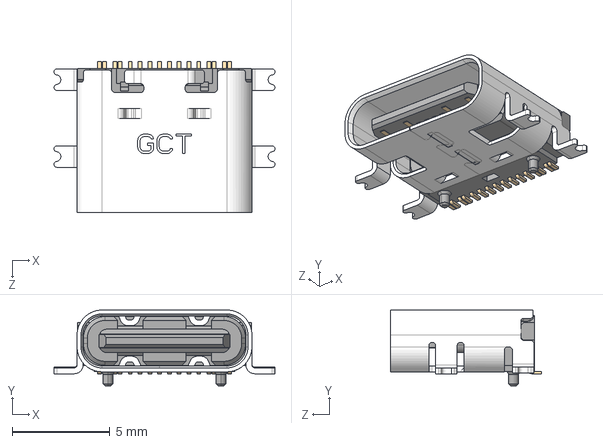
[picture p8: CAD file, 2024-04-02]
pcb/snapeda/models/USB4110GFA.step
11.3 x 3.89 x 7.70 mm

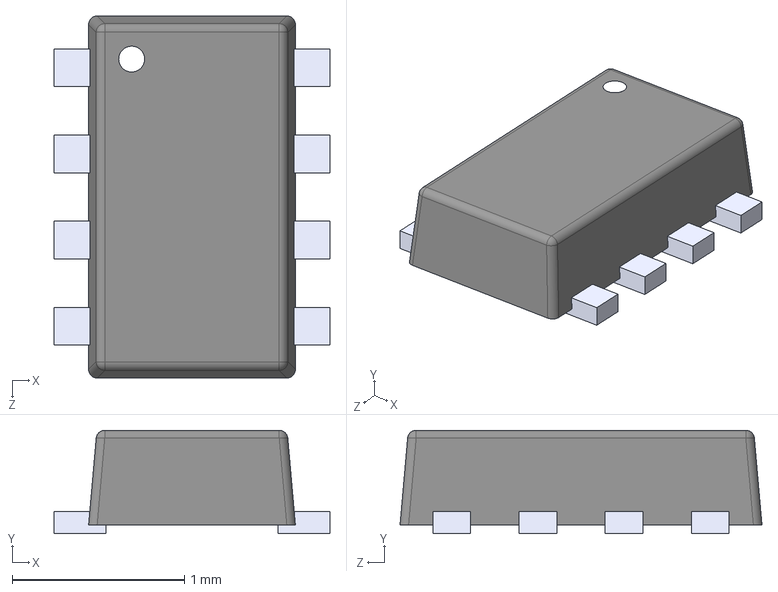
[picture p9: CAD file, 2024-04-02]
pcb/snapeda/models/TPS2117DRLR.step
1.60 x 0.6 x 2.10 mm

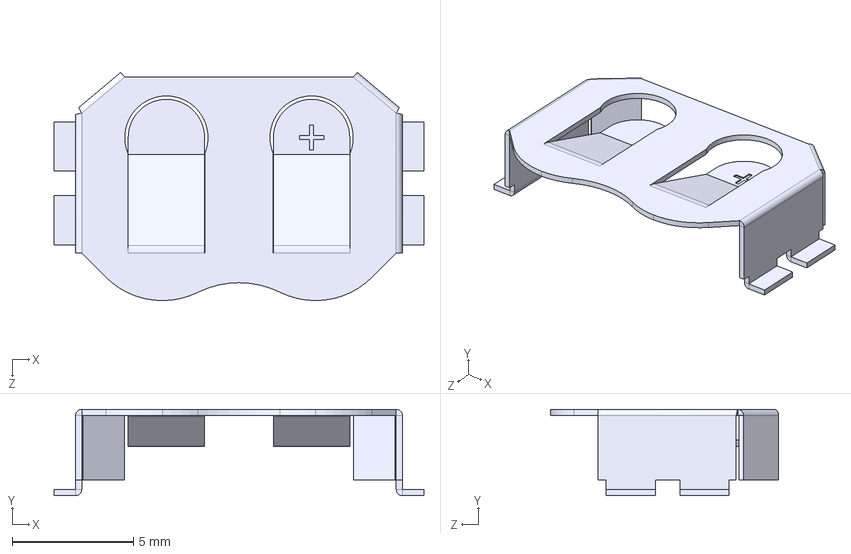
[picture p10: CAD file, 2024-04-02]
pcb/snapeda/models/BAT-HLD-012-SMT.step
15.2 x 3.56 x 9.40 mm

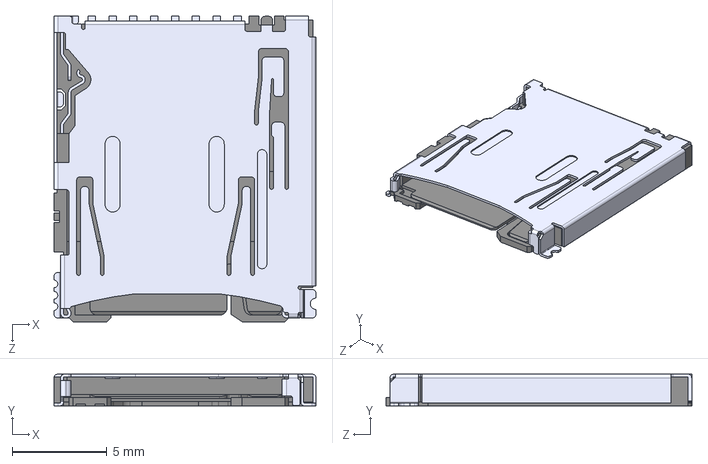
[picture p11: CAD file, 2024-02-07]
pcb/snapeda/models/DM3AT-SF-PEJM5--3DModel-STEP-418109.STEP
13.8 x 1.68 x 16.2 mm

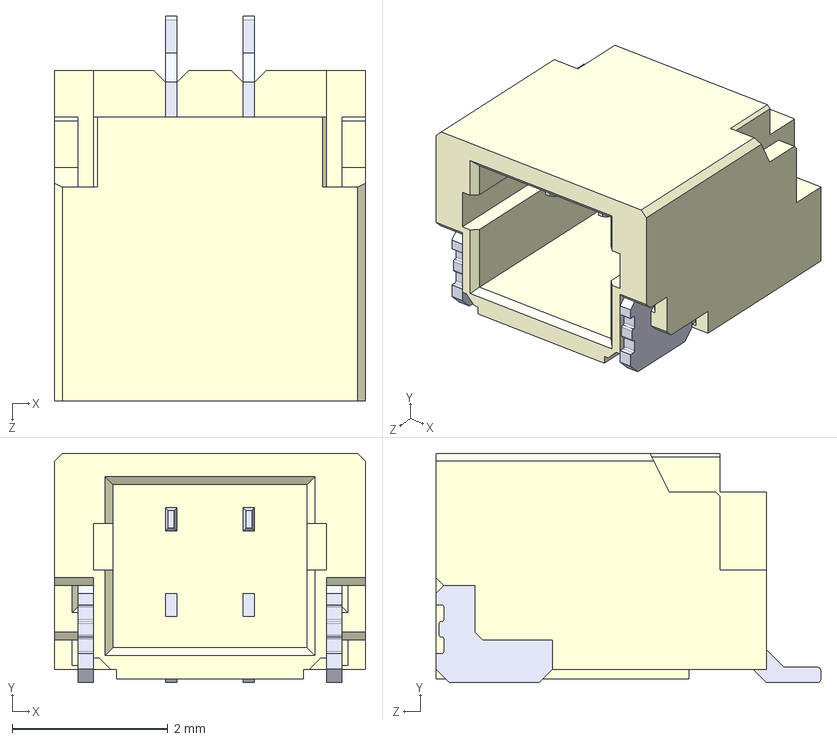
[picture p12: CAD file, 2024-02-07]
pcb/snapeda/models/SM02B-SRSS-TB_LF__SN_.step
4.00 x 2.95 x 4.95 mm

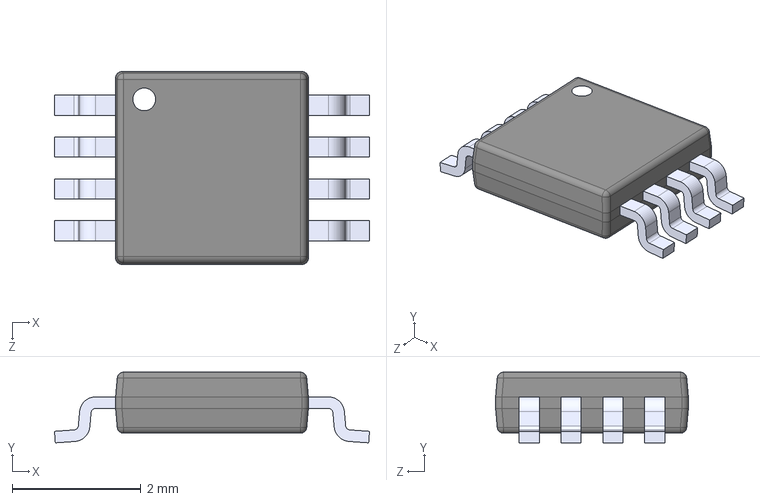
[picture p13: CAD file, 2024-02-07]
pcb/snapeda/models/TPS3619-50DGK.step
4.90 x 1.10 x 3.00 mm

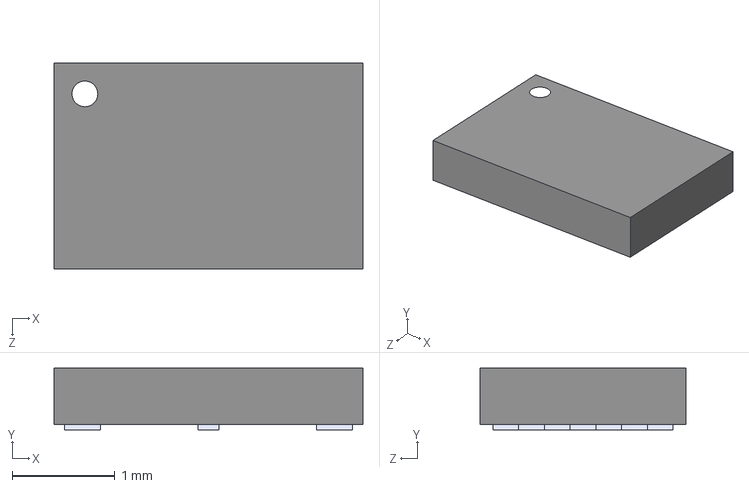
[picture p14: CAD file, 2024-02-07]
pcb/snapeda/models/W25Q16JVUXIQ.step
3.00 x 0.6 x 2.00 mm

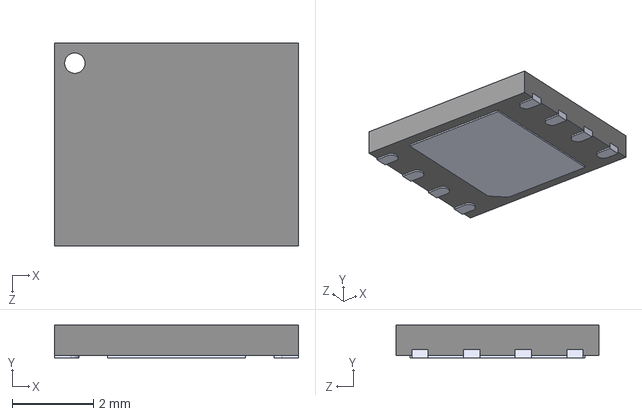
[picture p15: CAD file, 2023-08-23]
pcb/snapeda/models/W25Q16JVZPIQ.STEP
6.00 x 0.8 x 5.00 mm

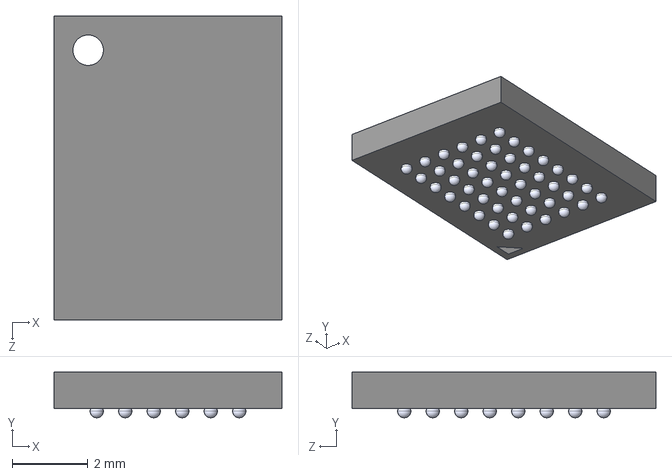
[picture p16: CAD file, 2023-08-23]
pcb/snapeda/models/IS66WVE4M16EBLL-70BLI.STEP
6.00 x 1.20 x 8.00 mm

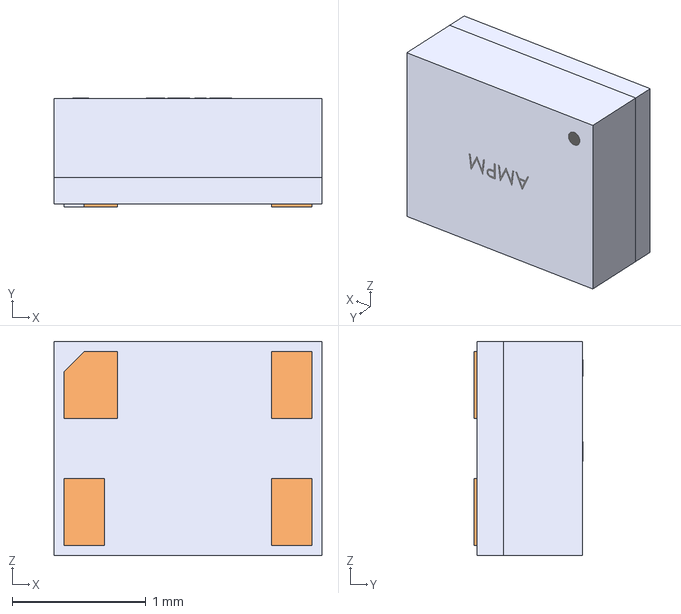
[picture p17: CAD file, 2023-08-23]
pcb/snapeda/models/AMPMAMPM_2.0 x 1.6 mm.step
2.00 x 0.811 x 1.60 mm

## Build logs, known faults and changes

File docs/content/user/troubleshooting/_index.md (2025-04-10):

---
title: 'Troubleshooting'
weight: 40
---

This page lists various nileswan issues that may be encountered, as well as solutions.

## Startup problems

### Console does not turn on with cartridge inserted

If no other cartridges work, this implies a fault with the console; fixing your console is outside the scope of this documentation.

If other cartridges work, the nileswan cartridge's contacts may be dirty. Clean up any dirt or grime on the contacts, then try re-inserting the cartridge.

The factory FPGA core data may be corrupt. This is a brick scenario which cannot be recovered in software; as such, you will need to use an external SPI flashing device to resolve it.

Finally, there may be a hardware fault with the device itself.

### Console displays a blank screen after finishing the splash screen sequence

This issue typically points to SPI flash data corruption.

The factory FPGA and IPL data may be intact. If so, follow the [Recovery -> Fixing corrupt update data](recovery#fixing-corrupt-update-data) guide, then install the latest firmware update.

If this alone does not help, the factory FPGA core data itself may be corrupt. In this case, software recovery cannot be guaranteed; as such, you will need to use an external SPI flashing device to resolve it.

## IPL problems

The initial program loader, or IPL, is responsible for loading an user-provided menu program from the removable storage card. In the case of an error, the screen turns black and an error message is displayed, like so:

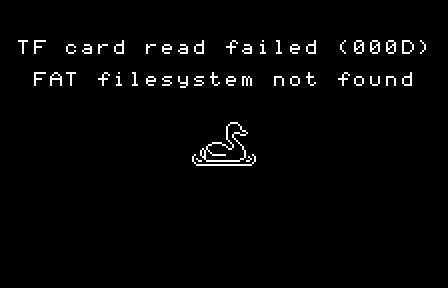
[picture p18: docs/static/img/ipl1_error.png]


Here are some common error messages. Note that an error may also point to a software bug, which may need to be reported to the developers.

**Storage not ready**

The removable storage card was not detected. Please try re-inserting it.

**Storage I/O error**

The removable storage card was detected, but an error occured while reading from it. This could point to a hardware fault with the card itself.

**FAT filesystem not found**

The removable storage card was detected, but a FAT16/FAT32 file system was not detected.

nileswan does not currently support exFAT file systems or GPT partition tables. If your card is formatted using exFAT, you will need to manually format it to use FAT32. This is typically a problem for cards larger than 32 GiB.

**File not found**

The menu file (`/NILESWAN/MENU.WS`) was not found on the cartridge.

## Other problems

### Persistent data (save data, date/time, ...) corruption

This issue implies the SRAM and/or MCU are not receiving power.

Make sure a battery is inserted and that the battery holds charge. If that does not resolve the issue, it may point to a software bug or hardware fault.

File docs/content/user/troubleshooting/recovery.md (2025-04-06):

---
title: 'Recovery features'
weight: 10
---

nileswan provides facilities to recover the cartridge in case of an unsuccessful flash operaiton or data corruption,
as well as recover the console's internal EEPROM.

## Fixing corrupt update data

The IPL1 (second stage bootloader) or updated FPGA bitstream data may be corrupted as the result of a failed update.
This can manifest as a blank screen or as a crash on the initial splash screen (before the menu program is loaded).

One can force the use of the factory IPL1 and FPGA bitstream by proceeding as follows:

1. Hold the button at the top of the cartridge.
2. While holding the button, turn on the console.
3. Keep holding the button until the initial splash screen appears.

From there, one can use any firmware update to reflash the update data.

## Recovery menu

nileswan also features a recovery menu. It can be accessed by holding the **X3 + B** button combination on startup (or **Esc + Up** on PCv2).

### Internal EEPROM recovery

Some console issues are caused by internal EEPROM corruption:

- a freeze on start can indicate corrupt splash screen data,
- LCD display issues can indicate corrupt LCD timing data on SC consoles with a TFT panel.

nileswan provides tools which may help in repairing a console with corrupt internal EEPROM data.

#### Disable custom splash

To disable custom splash on boot, one can use the following recovery feature:

1. Hold the button at the top of the cartridge.
2. While holding the button, turn on the console.

This forces the console's IPL to skip any splash screen data in the internal EEPROM.

A permanent solution is offered by the `Internal EEPROM recovery -> Disable custom splash` option in the cartridge recovery program.

#### Restore TFT panel data

To fix TFT panel display issues on SC consoles, one can use the `Internal EEPROM recovery -> Restore TFT panel data` option in the cartridge recovery program.

### Storage card management

This menu provides features related to managing the removable storage card, as well as evaluating its performance.

### Setup MCU boot flags

This is a manufacturing option used to configure the boot sequence of the microcontroller used on nileswan.

### Cartridge self-test

The cartridge comes with a set of self-test features used during manufacturing. These may allow you to diagnose certain hardware and firmware faults yourself. You can also run them in sequence with the `Run manufacturing tests` option.

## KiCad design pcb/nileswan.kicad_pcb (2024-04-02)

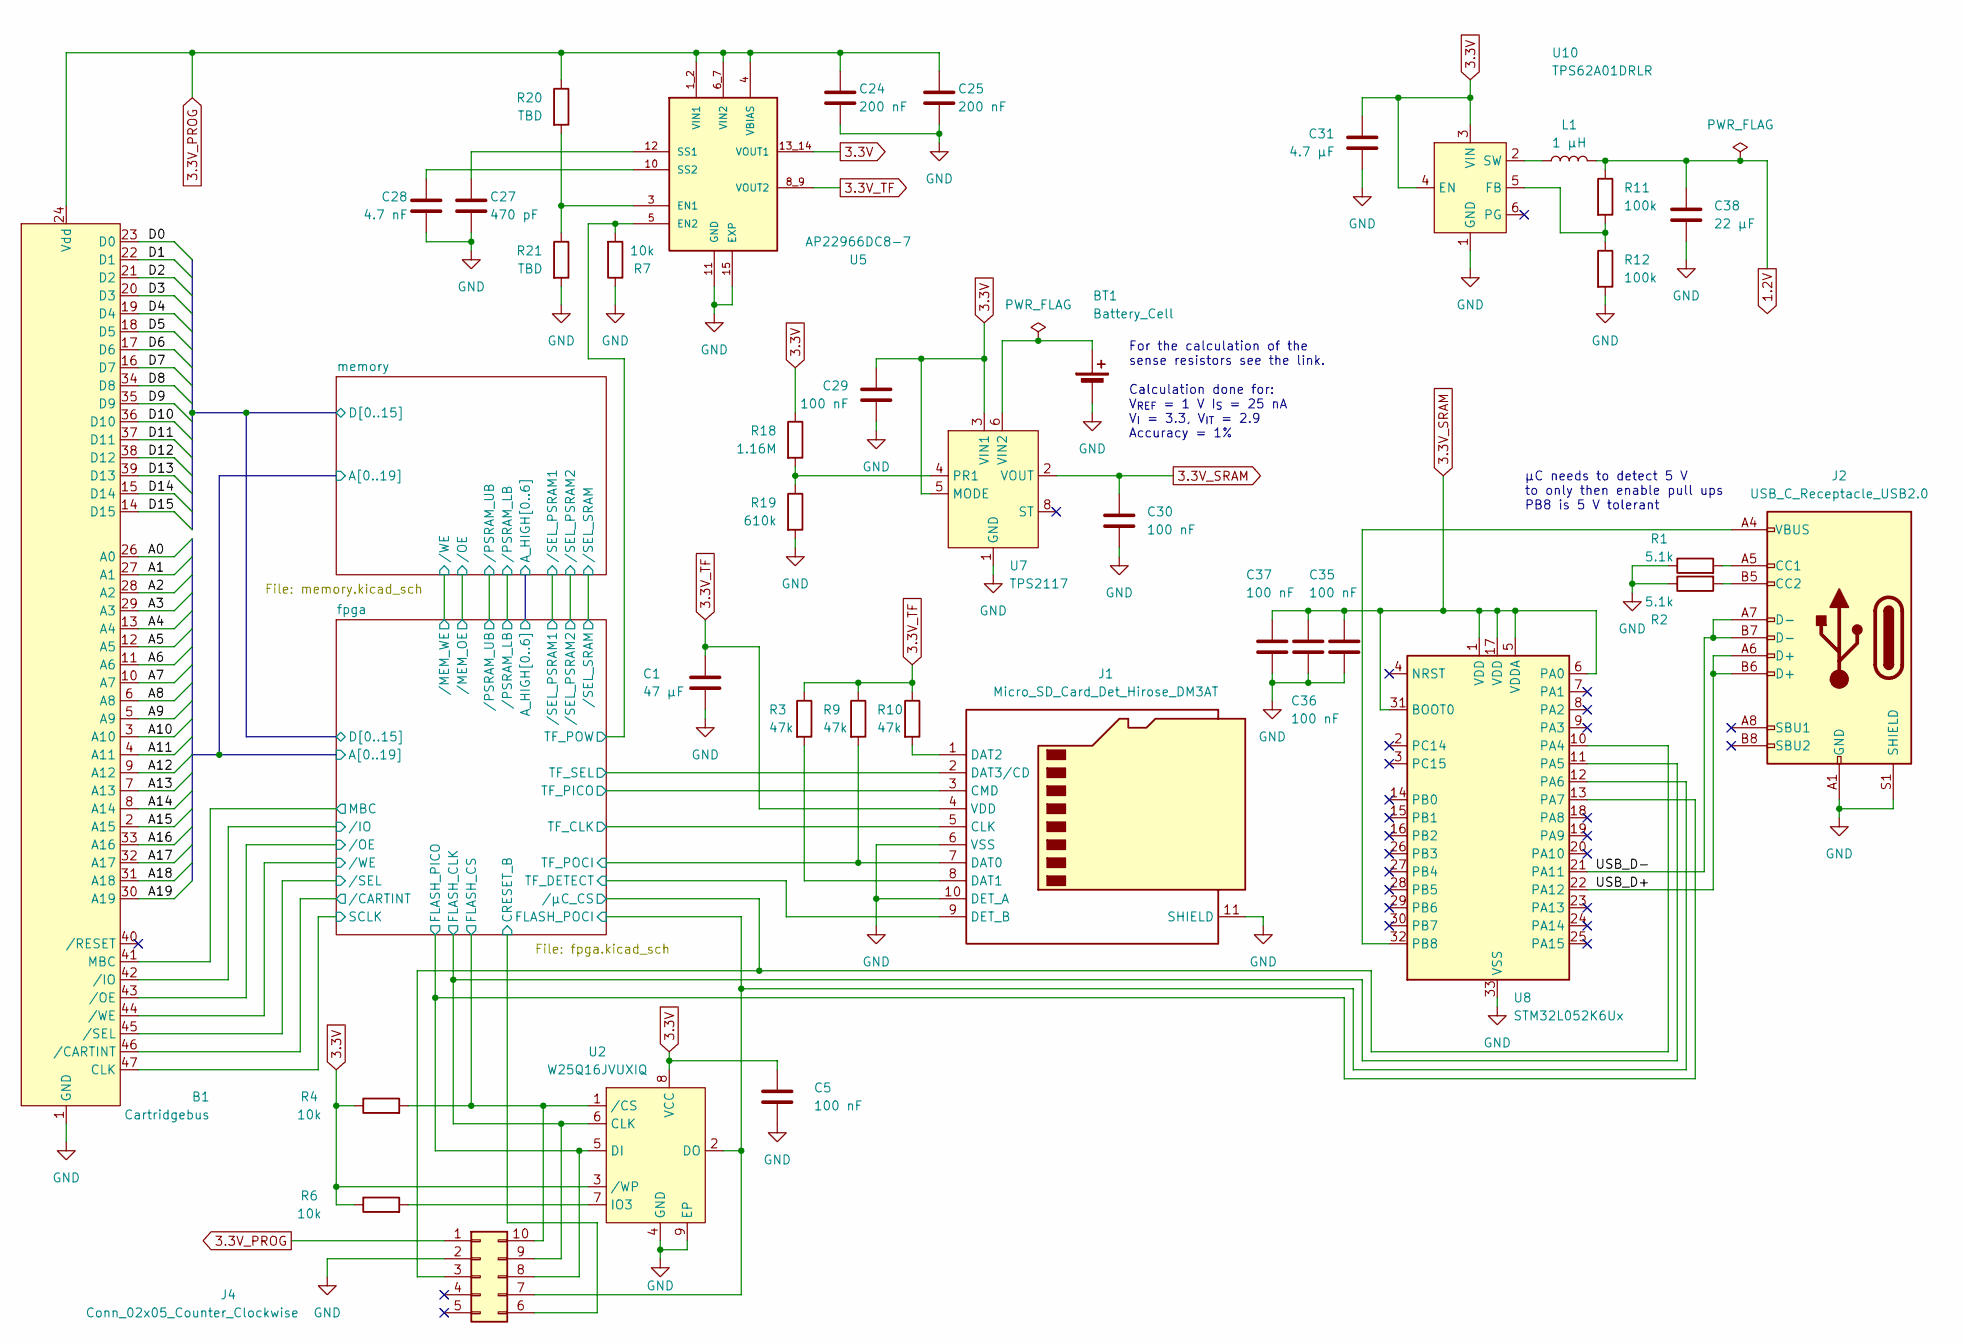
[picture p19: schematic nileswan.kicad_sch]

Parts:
B1: Cartridgebus; WSCartridgeBus
BT1: Battery_Cell; BAT_BAT-HLD-012-SMT
C1: 47 μF; C_0805_2012Metric
C5, C29, C30, C35, C36, C37: 100 nF; C_0402_1005Metric
C24, C25: 200 nF; C_0402_1005Metric
C27: 470 pF; C_0402_1005Metric
C28: 4.7 nF; C_0402_1005Metric
C31: 4.7 μF; C_0603_1608Metric
C38: 22 μF; C_0603_1608Metric
J1: Micro_SD_Card_Det_Hirose_DM3AT; microSD_HC_Hirose_DM3AT-SF-PEJM5
J2: USB_C_Receptacle_USB2.0; USB_C_Receptacle_GCT_USB4110
J4: Conn_02x05_Counter_Clockwise; Tag-Connect_TC2050-IDC-NL_2x05_P1.27mm_Vertical
L1: 1 μH; L_Murata_DFE201610P
R1, R2: 5.1k; R_0402_1005Metric
R3, R9, R10: 47k; R_0402_1005Metric
R4, R6, R7: 10k; R_0402_1005Metric
R11: 100k; R_0402_1005Metric
R12: 100k; C_0402_1005Metric
R18: 1.16M; R_0402_1005Metric
R19: 610k; R_0402_1005Metric
R20, R21: TBD; R_0402_1005Metric
U2: W25Q16JVUXIQ; SON50P300X200X60-9N
U5: AP22966DC8-7; IC_AP22966DC8-7; PARTREV 3-2
U7: TPS2117; SOTFL50P160X60-8N
U8: STM32L052K6Ux; QFN-32-1EP_5x5mm_P0.5mm_EP3.45x3.45mm
U10: TPS62A01DRLR; SOT-563

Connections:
1.2V: C38.1, L1.2, R11.1; also elsewhere on the board
3.3V: C5.1, C29.1, C31.1, R4.1, R6.1, R18.1, U2.3 (/WP), U2.8 (VCC), U5.13_14 (VOUT1), U7.3 (VIN1), U7.5 (MODE), U10.3 (VIN), U10.4 (EN); also elsewhere on the board
3.3V_PROG: B1.24 (Vdd), B1.25 (Vdd), C24.1, C25.1, J4.1, R20.1, U5.1_2 (VIN1), U5.4 (VBIAS), U5.6_7 (VIN2)
3.3V_SRAM: C30.1, C35.1, C36.1, C37.1, U7.2 (VOUT), U7.7 (VOUT), U8.1 (VDD), U8.5 (VDDA), U8.6 (PA0), U8.17 (VDD), U8.31 (BOOT0); also elsewhere on the board
3.3V_TF: C1.1, J1.4 (VDD), R3.1, R9.1, R10.1, U5.8_9 (VOUT2)
/USB_D+: J2.A6 (D+), J2.B6 (D+), U8.22 (PA12)
/USB_D-: J2.A7 (D-), J2.B7 (D-), U8.21 (PA11)
/fpga/A0: B1.26 (A0); also elsewhere on the board
/fpga/A1: B1.27 (A1); also elsewhere on the board
/fpga/A2: B1.28 (A2); also elsewhere on the board
/fpga/A3: B1.29 (A3); also elsewhere on the board
/fpga/A4: B1.13 (A4); also elsewhere on the board
/fpga/A5: B1.12 (A5); also elsewhere on the board
/fpga/A6: B1.11 (A6); also elsewhere on the board
/fpga/A7: B1.10 (A7); also elsewhere on the board
/fpga/A8: B1.6 (A8); also elsewhere on the board
/fpga/A9: B1.5 (A9); also elsewhere on the board
/fpga/A10: B1.3 (A10); also elsewhere on the board
/fpga/A11: B1.4 (A11); also elsewhere on the board
/fpga/A12: B1.9 (A12); also elsewhere on the board
/fpga/A13: B1.7 (A13); also elsewhere on the board
/fpga/A14: B1.8 (A14); also elsewhere on the board
/fpga/A15: B1.2 (A15); also elsewhere on the board
/fpga/A16: B1.33 (A16); also elsewhere on the board
/fpga/A17: B1.32 (A17); also elsewhere on the board
/fpga/A18: B1.31 (A18); also elsewhere on the board
/fpga/A19: B1.30 (A19); also elsewhere on the board
/fpga/CRESET_B: J4.6; also elsewhere on the board
/fpga/D0: B1.23 (D0); also elsewhere on the board
/fpga/D1: B1.22 (D1); also elsewhere on the board
/fpga/D2: B1.21 (D2); also elsewhere on the board
/fpga/D3: B1.20 (D3); also elsewhere on the board
/fpga/D4: B1.19 (D4); also elsewhere on the board
/fpga/D5: B1.18 (D5); also elsewhere on the board
/fpga/D6: B1.17 (D6); also elsewhere on the board
/fpga/D7: B1.16 (D7); also elsewhere on the board
/fpga/D8: B1.34 (D8); also elsewhere on the board
/fpga/D9: B1.35 (D9); also elsewhere on the board
/fpga/D10: B1.36 (D10); also elsewhere on the board
/fpga/D11: B1.37 (D11); also elsewhere on the board
/fpga/D12: B1.38 (D12); also elsewhere on the board
/fpga/D13: B1.39 (D13); also elsewhere on the board
/fpga/D14: B1.15 (D14); also elsewhere on the board
/fpga/D15: B1.14 (D15); also elsewhere on the board
/fpga/FLASH_CLK: J4.9, U2.6 (CLK), U8.11 (PA5); also elsewhere on the board
/fpga/FLASH_CS: J4.10, R4.2, U2.1 (/CS); also elsewhere on the board
/fpga/FLASH_PICO: J4.8, U2.5 (DI), U8.13 (PA7); also elsewhere on the board
/fpga/FLASH_POCI: J4.7, U2.2 (DO), U8.12 (PA6); also elsewhere on the board
/fpga/MBC: B1.41 (MBC); also elsewhere on the board
/fpga/SCLK: B1.47 (CLK); also elsewhere on the board
/fpga/TF_CLK: J1.5 (CLK); also elsewhere on the board
/fpga/TF_DETECT: J1.9 (DET_B); also elsewhere on the board
/fpga/TF_PICO: J1.3 (CMD); also elsewhere on the board
/fpga/TF_POCI: J1.7 (DAT0), R9.2; also elsewhere on the board
/fpga/TF_POW: R7.2, U5.5 (EN2); also elsewhere on the board
/fpga/TF_SEL: J1.2 (DAT3/CD); also elsewhere on the board
/fpga//CARTINT: B1.46 (/CARTINT); also elsewhere on the board
/fpga//IO: B1.42 (/IO); also elsewhere on the board
/fpga//OE: B1.43 (/OE); also elsewhere on the board
/fpga//SEL: B1.45 (/SEL); also elsewhere on the board
/fpga//WE: B1.44 (/WE); also elsewhere on the board
/fpga//μC_CS: J4.3, U8.10 (PA4); also elsewhere on the board
GND: B1.1 (GND), B1.48 (GND), BT1.2 (-), C1.2, C5.2, C24.2, C25.2, C27.2, C28.2, C29.2, C30.2, C31.2, C35.2, C36.2, C37.2, C38.2, J1.6 (VSS), J1.10 (DET_A), J1.11 (SHIELD), J2.A1 (GND), J2.A12 (GND), J2.B1 (GND), J2.B12 (GND), J2.S1 (SHIELD), J4.2, R1.1, R2.1, R7.1, R12.2, R19.2, R21.2, U2.4 (GND), U2.9 (EP), U5.11 (GND), U5.15 (EXP), U7.1 (GND), U8.33 (VSS), U10.1 (GND); also elsewhere on the board
unnamed: BT1.1 (+), U7.6 (VIN2)
unnamed: J1.8 (DAT1), R3.2
unnamed: J1.1 (DAT2), R10.2
unnamed: J2.A5 (CC1), R1.2
unnamed: J2.B5 (CC2), R2.2
unnamed: R6.2, U2.7 (IO3)
unnamed: R20.2, R21.1, U5.3 (EN1)
unnamed: C27.1, U5.12 (SS1)
unnamed: C28.1, U5.10 (SS2)
unnamed: R18.2, R19.1, U7.4 (PR1)
unnamed: J2.A4 (VBUS), J2.A9 (VBUS), J2.B4 (VBUS), J2.B9 (VBUS), U8.32 (PB8)
unnamed: R11.2, R12.1, U10.5 (FB)
unnamed: L1.1, U10.2 (SW)

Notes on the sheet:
μC needs to detect 5 V to only then enable pull ups PB8 is 5 V tolerant
For the calculation of the sense resistors see the link. Calculation done for: V_{REF} = 1 V I_{S} = 25 nA V_{I} = 3.3, V_{IT} = 2.9 Accuracy = 1%

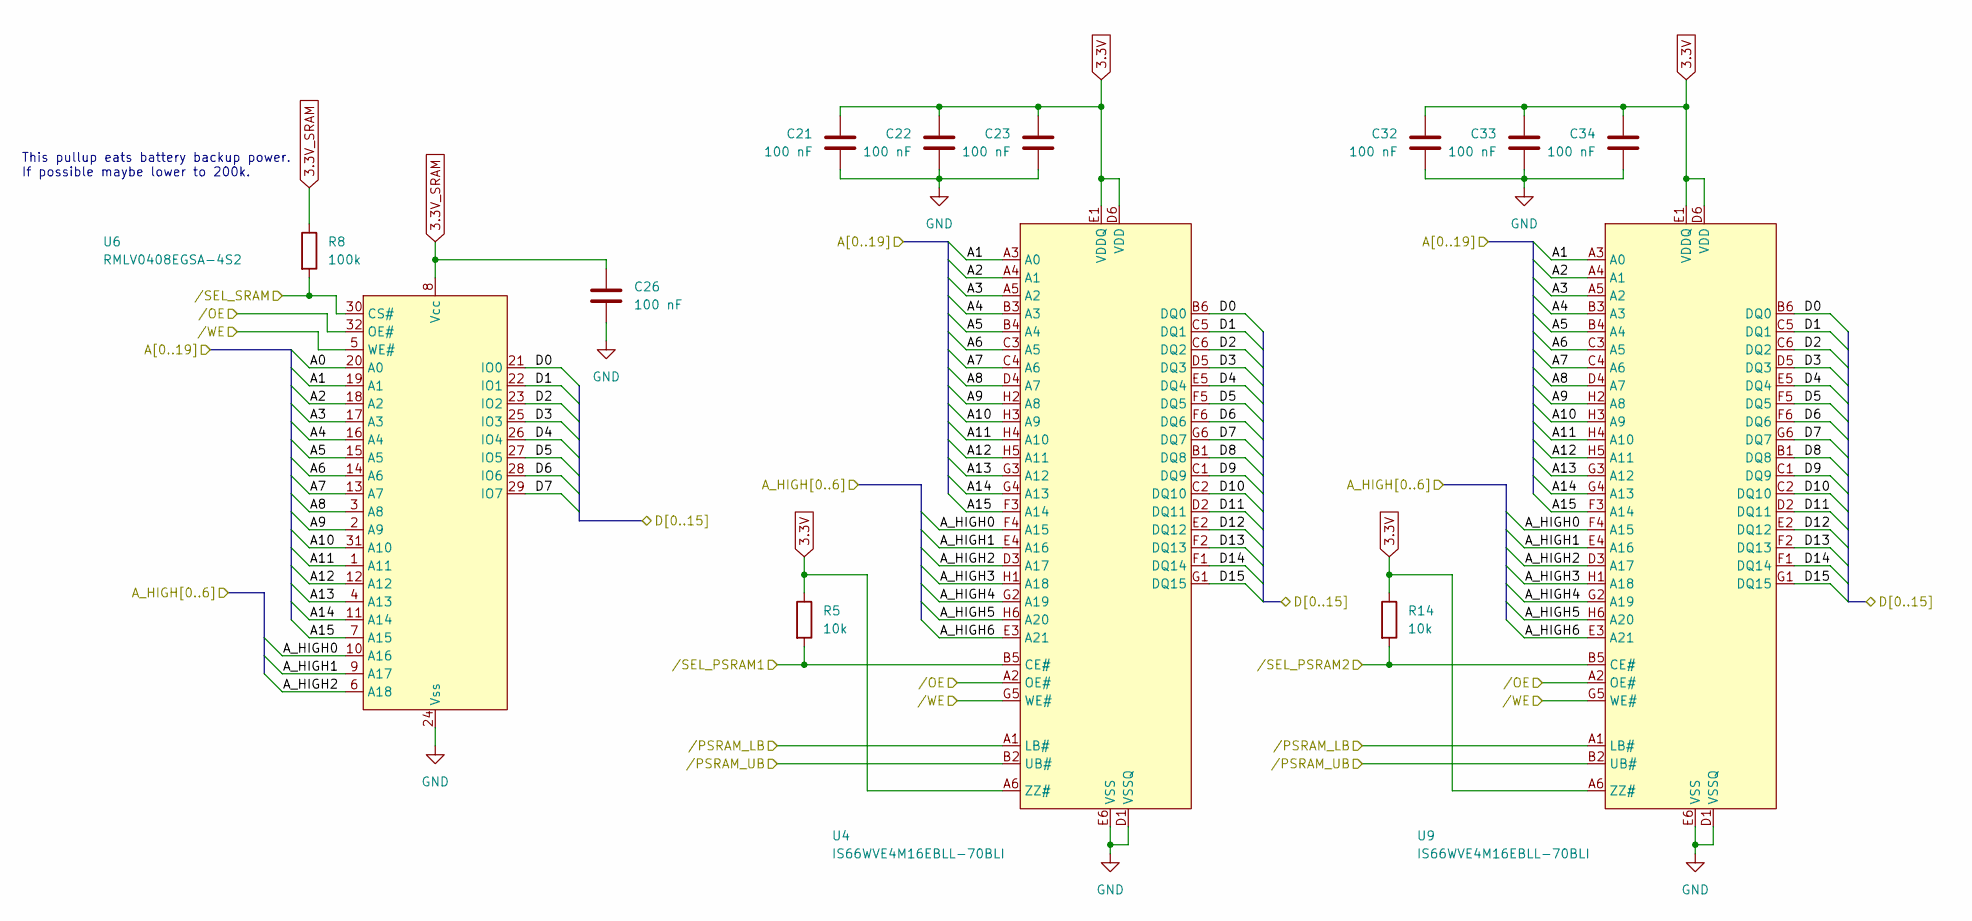
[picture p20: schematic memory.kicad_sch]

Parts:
C21, C22, C23, C26, C32, C33, C34: 100 nF; C_0402_1005Metric
R5, R14: 10k; R_0402_1005Metric
R8: 100k; R_0402_1005Metric
U4, U9: IS66WVE4M16EBLL-70BLI; BGA-48_6x8_6.0x8.0mm
U6: RMLV0408EGSA-4S2; sTSOP-32

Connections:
3.3V: C21.2, C22.2, C23.2, C32.2, C33.2, C34.2, R5.1, R14.1, U4.A6 (ZZ#), U4.D6 (VDD), U4.E1 (VDDQ), U9.A6 (ZZ#), U9.D6 (VDD), U9.E1 (VDDQ); also elsewhere on the board
3.3V_SRAM: C26.2, R8.1, U6.8 (Vcc); also elsewhere on the board
/fpga/A0: U6.20 (A0); also elsewhere on the board
/fpga/A1: U4.A3 (A0), U6.19 (A1), U9.A3 (A0); also elsewhere on the board
/fpga/A2: U4.A4 (A1), U6.18 (A2), U9.A4 (A1); also elsewhere on the board
/fpga/A3: U4.A5 (A2), U6.17 (A3), U9.A5 (A2); also elsewhere on the board
/fpga/A4: U4.B3 (A3), U6.16 (A4), U9.B3 (A3); also elsewhere on the board
/fpga/A5: U4.B4 (A4), U6.15 (A5), U9.B4 (A4); also elsewhere on the board
/fpga/A6: U4.C3 (A5), U6.14 (A6), U9.C3 (A5); also elsewhere on the board
/fpga/A7: U4.C4 (A6), U6.13 (A7), U9.C4 (A6); also elsewhere on the board
/fpga/A8: U4.D4 (A7), U6.3 (A8), U9.D4 (A7); also elsewhere on the board
/fpga/A9: U4.H2 (A8), U6.2 (A9), U9.H2 (A8); also elsewhere on the board
/fpga/A10: U4.H3 (A9), U6.31 (A10), U9.H3 (A9); also elsewhere on the board
/fpga/A11: U4.H4 (A10), U6.1 (A11), U9.H4 (A10); also elsewhere on the board
/fpga/A12: U4.H5 (A11), U6.12 (A12), U9.H5 (A11); also elsewhere on the board
/fpga/A13: U4.G3 (A12), U6.4 (A13), U9.G3 (A12); also elsewhere on the board
/fpga/A14: U4.G4 (A13), U6.11 (A14), U9.G4 (A13); also elsewhere on the board
/fpga/A15: U4.F3 (A14), U6.7 (A15), U9.F3 (A14); also elsewhere on the board
/fpga/A_HIGH0: U4.F4 (A15), U6.10 (A16), U9.F4 (A15); also elsewhere on the board
/fpga/A_HIGH1: U4.E4 (A16), U6.9 (A17), U9.E4 (A16); also elsewhere on the board
/fpga/A_HIGH2: U4.D3 (A17), U6.6 (A18), U9.D3 (A17); also elsewhere on the board
/fpga/A_HIGH3: U4.H1 (A18), U9.H1 (A18); also elsewhere on the board
/fpga/A_HIGH4: U4.G2 (A19), U9.G2 (A19); also elsewhere on the board
/fpga/A_HIGH5: U4.H6 (A20), U9.H6 (A20); also elsewhere on the board
/fpga/A_HIGH6: U4.E3 (A21), U9.E3 (A21); also elsewhere on the board
/fpga/D0: U4.B6 (DQ0), U6.21 (IO0), U9.B6 (DQ0); also elsewhere on the board
/fpga/D1: U4.C5 (DQ1), U6.22 (IO1), U9.C5 (DQ1); also elsewhere on the board
/fpga/D2: U4.C6 (DQ2), U6.23 (IO2), U9.C6 (DQ2); also elsewhere on the board
/fpga/D3: U4.D5 (DQ3), U6.25 (IO3), U9.D5 (DQ3); also elsewhere on the board
/fpga/D4: U4.E5 (DQ4), U6.26 (IO4), U9.E5 (DQ4); also elsewhere on the board
/fpga/D5: U4.F5 (DQ5), U6.27 (IO5), U9.F5 (DQ5); also elsewhere on the board
/fpga/D6: U4.F6 (DQ6), U6.28 (IO6), U9.F6 (DQ6); also elsewhere on the board
/fpga/D7: U4.G6 (DQ7), U6.29 (IO7), U9.G6 (DQ7); also elsewhere on the board
/fpga/D8: U4.B1 (DQ8), U9.B1 (DQ8); also elsewhere on the board
/fpga/D9: U4.C1 (DQ9), U9.C1 (DQ9); also elsewhere on the board
/fpga/D10: U4.C2 (DQ10), U9.C2 (DQ10); also elsewhere on the board
/fpga/D11: U4.D2 (DQ11), U9.D2 (DQ11); also elsewhere on the board
/fpga/D12: U4.E2 (DQ12), U9.E2 (DQ12); also elsewhere on the board
/fpga/D13: U4.F2 (DQ13), U9.F2 (DQ13); also elsewhere on the board
/fpga/D14: U4.F1 (DQ14), U9.F1 (DQ14); also elsewhere on the board
/fpga/D15: U4.G1 (DQ15), U9.G1 (DQ15); also elsewhere on the board
/fpga//MEM_OE: U4.A2 (OE#), U6.32 (OE#), U9.A2 (OE#); also elsewhere on the board
/fpga//MEM_WE: U4.G5 (WE#), U6.5 (WE#), U9.G5 (WE#); also elsewhere on the board
/fpga//PSRAM_LB: U4.A1 (LB#), U9.A1 (LB#); also elsewhere on the board
/fpga//PSRAM_UB: U4.B2 (UB#), U9.B2 (UB#); also elsewhere on the board
/fpga//SEL_PSRAM1: R5.2, U4.B5 (CE#); also elsewhere on the board
/fpga//SEL_PSRAM2: R14.2, U9.B5 (CE#); also elsewhere on the board
/fpga//SEL_SRAM: R8.2, U6.30 (CS#); also elsewhere on the board
GND: C21.1, C22.1, C23.1, C26.1, C32.1, C33.1, C34.1, U4.D1 (VSSQ), U4.E6 (VSS), U6.24 (Vss), U9.D1 (VSSQ), U9.E6 (VSS); also elsewhere on the board

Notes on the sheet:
This pullup eats battery backup power. If possible maybe lower to 200k.

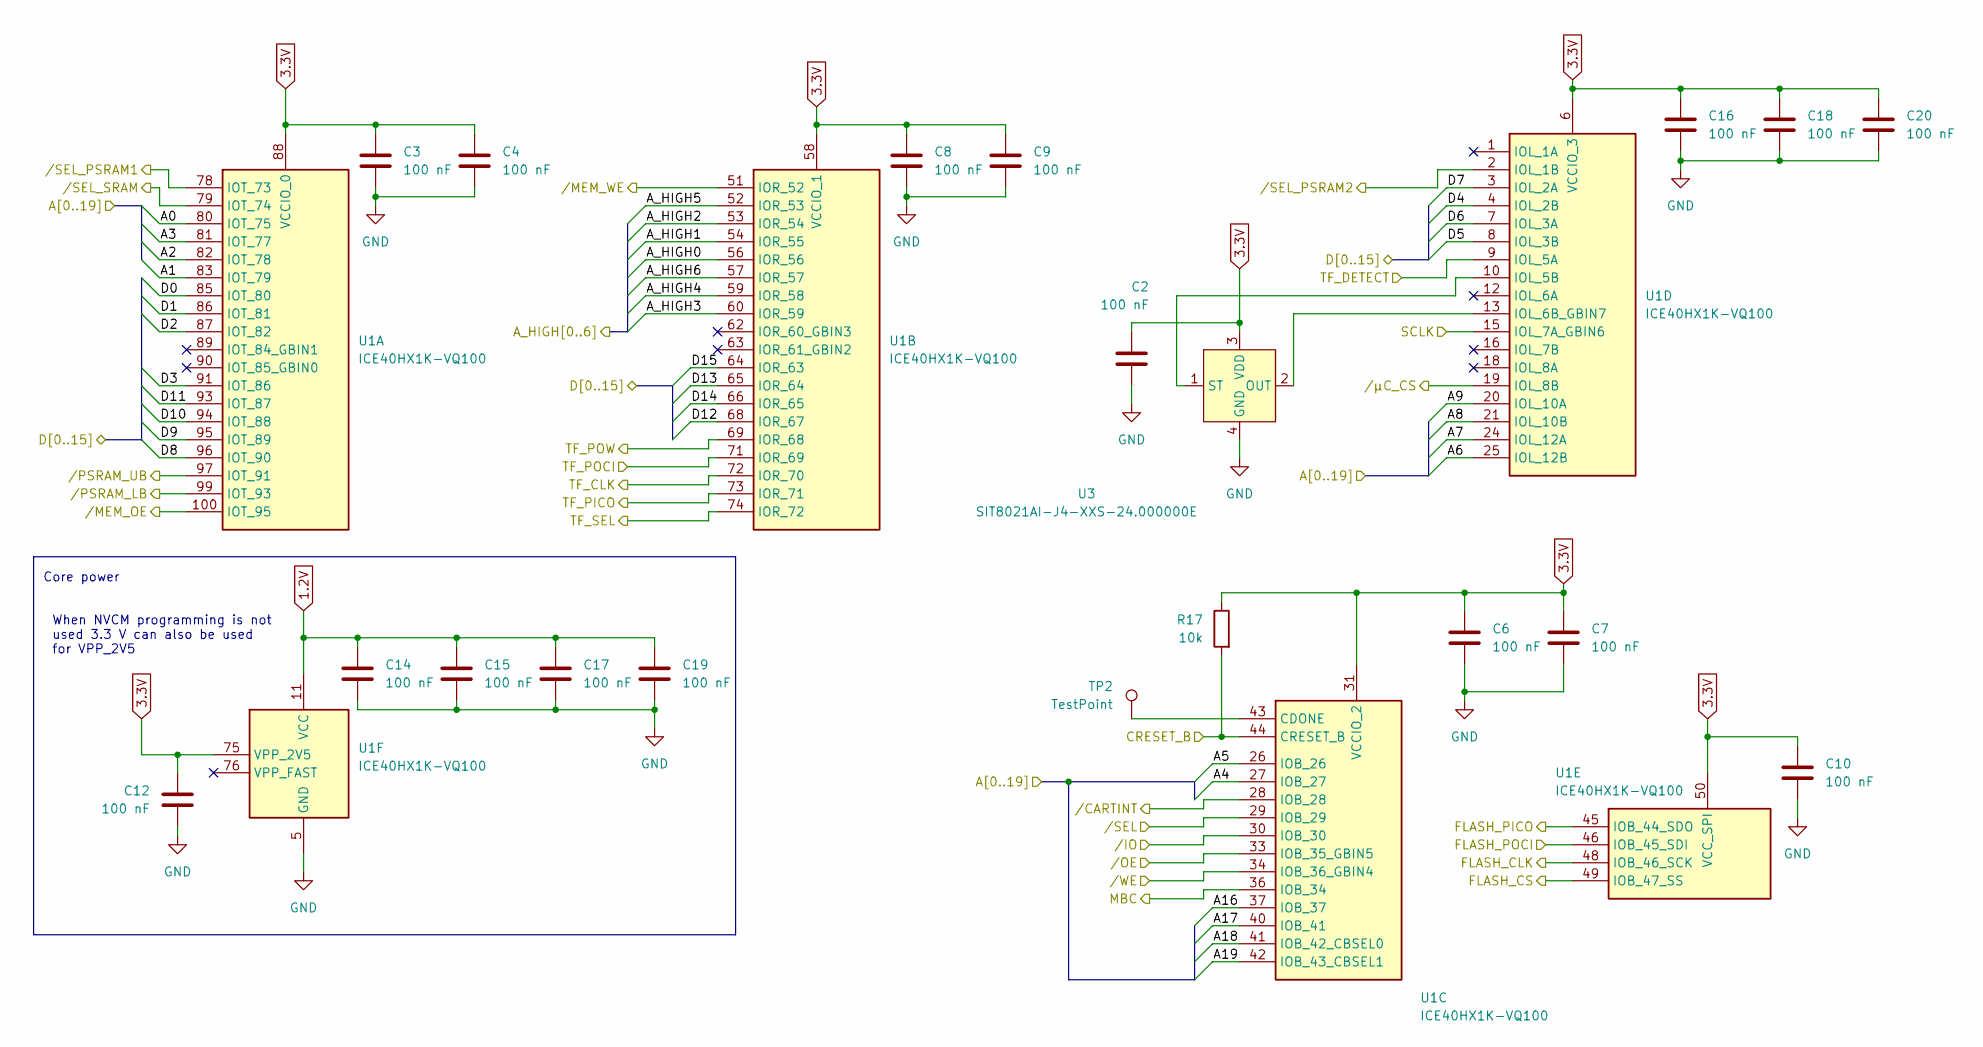
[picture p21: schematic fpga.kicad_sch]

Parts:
C2, C3, C4, C6, C7, C8, C9, C10, C12, C14, C15, C16, C17, C18, C19, C20: 100 nF; C_0402_1005Metric
R17: 10k; R_0402_1005Metric
TP2: TestPoint; TestPoint_Pad_D1.0mm
U1: ICE40HX1K-VQ100; VQFP-100_14x14mm_P0.5mm
U3: SIT8021AI-J4-XXS-24.000000E; BGA4N41X100P2X2_84X154X60N

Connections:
1.2V: C14.1, C15.1, C17.1, C19.1, U1.11 (VCC), U1.35 (VCC), U1.61 (VCC), U1.77 (VCC); also elsewhere on the board
3.3V: C2.1, C3.1, C4.1, C6.1, C7.1, C8.1, C9.1, C10.1, C12.1, C16.1, C18.1, C20.1, R17.1, U1.6 (VCCIO_3), U1.14 (VCCIO_3), U1.22 (VCCIO_3), U1.31 (VCCIO_2), U1.38 (VCCIO_2), U1.50 (VCC_SPI), U1.58 (VCCIO_1), U1.67 (VCCIO_1), U1.75 (VPP_2V5), U1.88 (VCCIO_0), U1.92 (VCCIO_0), U3.3 (VDD); also elsewhere on the board
/fpga/A0: U1.80 (IOT_75); also elsewhere on the board
/fpga/A1: U1.83 (IOT_79); also elsewhere on the board
/fpga/A2: U1.82 (IOT_78); also elsewhere on the board
/fpga/A3: U1.81 (IOT_77); also elsewhere on the board
/fpga/A4: U1.27 (IOB_27); also elsewhere on the board
/fpga/A5: U1.26 (IOB_26); also elsewhere on the board
/fpga/A6: U1.25 (IOL_12B); also elsewhere on the board
/fpga/A7: U1.24 (IOL_12A); also elsewhere on the board
/fpga/A8: U1.21 (IOL_10B); also elsewhere on the board
/fpga/A9: U1.20 (IOL_10A); also elsewhere on the board
/fpga/A16: U1.37 (IOB_37); also elsewhere on the board
/fpga/A17: U1.40 (IOB_41); also elsewhere on the board
/fpga/A18: U1.41 (IOB_42_CBSEL0); also elsewhere on the board
/fpga/A19: U1.42 (IOB_43_CBSEL1); also elsewhere on the board
/fpga/A_HIGH0: U1.56 (IOR_56); also elsewhere on the board
/fpga/A_HIGH1: U1.54 (IOR_55); also elsewhere on the board
/fpga/A_HIGH2: U1.53 (IOR_54); also elsewhere on the board
/fpga/A_HIGH3: U1.60 (IOR_59); also elsewhere on the board
/fpga/A_HIGH4: U1.59 (IOR_58); also elsewhere on the board
/fpga/A_HIGH5: U1.52 (IOR_53); also elsewhere on the board
/fpga/A_HIGH6: U1.57 (IOR_57); also elsewhere on the board
/fpga/CRESET_B: R17.2, U1.44 (CRESET_B); also elsewhere on the board
/fpga/D0: U1.85 (IOT_80); also elsewhere on the board
/fpga/D1: U1.86 (IOT_81); also elsewhere on the board
/fpga/D2: U1.87 (IOT_82); also elsewhere on the board
/fpga/D3: U1.91 (IOT_86); also elsewhere on the board
/fpga/D4: U1.4 (IOL_2B); also elsewhere on the board
/fpga/D5: U1.8 (IOL_3B); also elsewhere on the board
/fpga/D6: U1.7 (IOL_3A); also elsewhere on the board
/fpga/D7: U1.3 (IOL_2A); also elsewhere on the board
/fpga/D8: U1.96 (IOT_90); also elsewhere on the board
/fpga/D9: U1.95 (IOT_89); also elsewhere on the board
/fpga/D10: U1.94 (IOT_88); also elsewhere on the board
/fpga/D11: U1.93 (IOT_87); also elsewhere on the board
/fpga/D12: U1.68 (IOR_67); also elsewhere on the board
/fpga/D13: U1.65 (IOR_64); also elsewhere on the board
/fpga/D14: U1.66 (IOR_65); also elsewhere on the board
/fpga/D15: U1.64 (IOR_63); also elsewhere on the board
/fpga/FLASH_CLK: U1.48 (IOB_46_SCK); also elsewhere on the board
/fpga/FLASH_CS: U1.49 (IOB_47_SS); also elsewhere on the board
/fpga/FLASH_PICO: U1.45 (IOB_44_SDO); also elsewhere on the board
/fpga/FLASH_POCI: U1.46 (IOB_45_SDI); also elsewhere on the board
/fpga/MBC: U1.36 (IOB_34); also elsewhere on the board
/fpga/SCLK: U1.15 (IOL_7A_GBIN6); also elsewhere on the board
/fpga/TF_CLK: U1.72 (IOR_70); also elsewhere on the board
/fpga/TF_DETECT: U1.9 (IOL_5A); also elsewhere on the board
/fpga/TF_PICO: U1.73 (IOR_71); also elsewhere on the board
/fpga/TF_POCI: U1.71 (IOR_69); also elsewhere on the board
/fpga/TF_POW: U1.69 (IOR_68); also elsewhere on the board
/fpga/TF_SEL: U1.74 (IOR_72); also elsewhere on the board
/fpga//CARTINT: U1.28 (IOB_28); also elsewhere on the board
/fpga//IO: U1.30 (IOB_30); also elsewhere on the board
/fpga//MEM_OE: U1.100 (IOT_95); also elsewhere on the board
/fpga//MEM_WE: U1.51 (IOR_52); also elsewhere on the board
/fpga//OE: U1.33 (IOB_35_GBIN5); also elsewhere on the board
/fpga//PSRAM_LB: U1.99 (IOT_93); also elsewhere on the board
/fpga//PSRAM_UB: U1.97 (IOT_91); also elsewhere on the board
/fpga//SEL: U1.29 (IOB_29); also elsewhere on the board
/fpga//SEL_PSRAM1: U1.78 (IOT_73); also elsewhere on the board
/fpga//SEL_PSRAM2: U1.2 (IOL_1B); also elsewhere on the board
/fpga//SEL_SRAM: U1.79 (IOT_74); also elsewhere on the board
/fpga//WE: U1.34 (IOB_36_GBIN4); also elsewhere on the board
/fpga//μC_CS: U1.19 (IOL_8B); also elsewhere on the board
GND: C2.2, C3.2, C4.2, C6.2, C7.2, C8.2, C9.2, C10.2, C12.2, C14.2, C15.2, C16.2, C17.2, C18.2, C19.2, C20.2, U1.5 (GND), U1.17 (GND), U1.23 (GND), U1.32 (GND), U1.39 (GND), U1.47 (GND), U1.55 (GND), U1.70 (GND), U1.84 (GND), U1.98 (GND), U3.4 (GND); also elsewhere on the board
unnamed: TP2.1, U1.43 (CDONE)
unnamed: U1.10 (IOL_5B), U3.1 (ST)
unnamed: U1.13 (IOL_6B_GBIN7), U3.2 (OUT)

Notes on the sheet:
Core power
When NVCM programming is not used 3.3 V can also be used for VPP_2V5

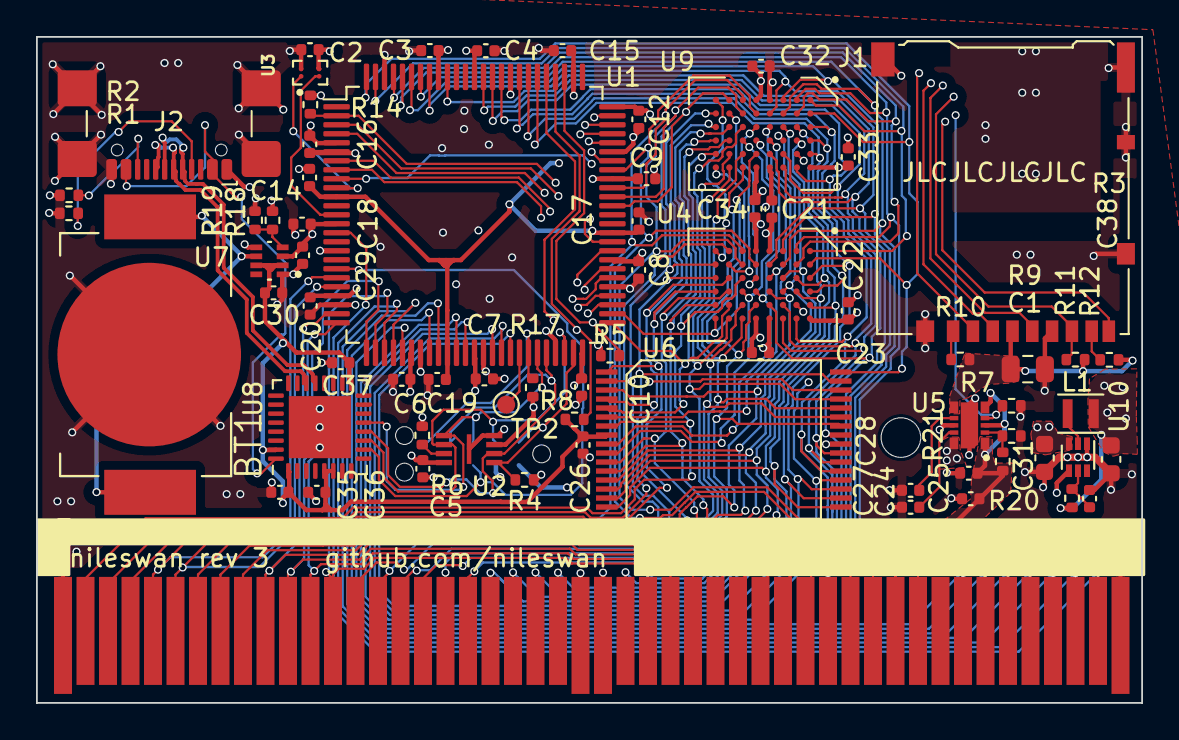
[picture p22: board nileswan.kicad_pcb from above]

Board: 4 copper layers, 61.4 x 37.0 mm, 71 parts (1 on the bottom side), 93 nets.

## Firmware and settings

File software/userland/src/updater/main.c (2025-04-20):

/**
 * Copyright (c) 2024 Adrian Siekierka
 *
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
 * You should have received a copy of the GNU General Public License along
 * with Nileswan Updater. If not, see <https://www.gnu.org/licenses/>.
 */

#include <nile/mcu.h>
#include <stdarg.h>
#include <stdio.h>
#include <string.h>
#include <wonderful.h>
#include <ws.h>
#include <wsx/zx0.h>
#include "crc16.h"
#include "manifest.h"
#include "nile.h"
#include "nilefs.h"
#include "console.h"
#include "input.h"
#include "strings.h"

#define IRAM_IMPLEMENTATION
#include "iram.h"

#define UNPACK_BUFFER ((uint8_t __far*) MK_FP(0x1000, 0x0000))

uint8_t update_manifest_data[512];
uint32_t flash_id;
bool mcu_restarted = false;
int update_part;
bool update_verify;

static void update_halt(void) {
	cpu_irq_disable();
	while(1) cpu_halt();
}

static void updater_early_error(const char __far *text, uint16_t code) {
	console_print_status(false);
	console_print_newline();
	console_printf(0, text, code);
	update_halt();
}

static void updater_flash_error(void) {
	console_print_status(false);
	console_print_newline();
	console_print(0, s_fatal_error);
	update_halt();
}

static void extract_um_cmd_flash(um_flash_cmd_t *cmd) {
	console_printf(0, update_verify ? s_verifying_part : s_unpacking_part, update_part);
	// Extract data to SRAM
	outportw(IO_BANK_2003_RAM, 0);
	if (cmd->cmd == UM_CMD_PACKED_FLASH) {
		wsx_zx0_decompress(UNPACK_BUFFER, MK_FP(cmd->load_segment, 0));
	} else {
		memcpy(UNPACK_BUFFER, MK_FP(cmd->load_segment, 0), cmd->unpacked_length);
	}
	// Calculate CRC16 sum
	uint16_t actual_crc = crc16(UNPACK_BUFFER, cmd->unpacked_length, 0);
	if (actual_crc != cmd->expected_crc) {
		console_print_status(false);
		console_print_newline();
		console_printf(0, s_crc_error_part, update_part);
		console_printf(0, s_crc_error_a_e, actual_crc, cmd->expected_crc);
		update_halt();
	}
}

static void run_um_cmd_flash(um_flash_cmd_t *cmd) {
	uint8_t flash_buffer[256];
	uint8_t verify_buffer[256];

	if (cmd->board_revision < 0x100 && inportb(IO_NILE_BOARD_REVISION) != cmd->board_revision)
		return;

	extract_um_cmd_flash(cmd);

	uint32_t start_address = cmd->flash_address;
	if (start_address & 0xFF) {
		updater_early_error(s_corrupt_data, start_address & 0xFF);
	}

	if (!update_verify) {
		console_print_status(true);
		console_print_newline();
		console_printf(0, s_erasing_part, update_part);

		uint32_t end_address = start_address + cmd->unpacked_length;
		uint32_t erase_address = (start_address & ~0xFFF);
		while (erase_address < end_address) {
			if (!nile_flash_erase_part(NILE_FLASH_CMD_ERASE_4K, erase_address)) {
				updater_flash_error();
			}
			erase_address += 4096;
		}

		console_print_status(true);
		console_print_newline();
		console_printf(0, s_flashing_part, update_part);

		uint32_t i = 0;
		while (start_address < end_address) {
			uint32_t len = end_address - start_address;
			if (len > sizeof(flash_buffer)) len = sizeof(flash_buffer);

			outportw(IO_BANK_2003_RAM, 0);
			memcpy(flash_buffer, UNPACK_BUFFER + i, len);
			if (!nile_flash_write_page(flash_buffer, start_address, len)) {
				updater_flash_error();
			}
			if (!nile_flash_read(verify_buffer, start_address, len)) {
				updater_flash_error();
			}

			outportw(IO_BANK_2003_RAM, 0);
			if (memcmp(verify_buffer, UNPACK_BUFFER + i, len)) {
				updater_flash_error();
			}

			start_address += len;
			i += len;
		}
	}

	console_print_status(true);
	console_print_newline();
}

static void run_um_cmd_mcu_flash(um_flash_cmd_t *cmd) {
	uint8_t flash_buffer[128];
	uint8_t verify_buffer[128];

	if (cmd->board_revision < 0x100 && inportb(IO_NILE_BOARD_REVISION) != cmd->board_revision)
		return;

	extract_um_cmd_flash(cmd);

	uint32_t start_address = cmd->flash_address;
	if (start_address & (NILE_MCU_FLASH_PAGE_SIZE - 1)) {
		updater_early_error(s_corrupt_data, start_address & (NILE_MCU_FLASH_PAGE_SIZE - 1));
	}

	if (!mcu_restarted) {
		console_print_status(true);
		console_print_newline();
		console_print(0, s_rebooting_mcu);

		if (!nile_mcu_reset(true)) {
			updater_flash_error();
		}

		mcu_restarted = true;
	}

	if (!update_verify) {
		console_print_status(true);
		console_print_newline();
		console_printf(0, s_erasing_part, update_part);

		uint32_t end_address = start_address + cmd->unpacked_length;
		uint16_t page_start = start_address / NILE_MCU_FLASH_PAGE_SIZE;
		uint16_t page_count = (end_address + NILE_MCU_FLASH_PAGE_SIZE - 1 - start_address) / NILE_MCU_FLASH_PAGE_SIZE;

		if (!nile_mcu_boot_erase_memory(page_start, page_count))
			updater_flash_error();

		console_print_status(true);
		console_print_newline();
		console_printf(0, s_flashing_part, update_part);

		start_address += NILE_MCU_FLASH_START;
		end_address += NILE_MCU_FLASH_START;

		uint32_t i = 0;
		while (start_address < end_address) {
			uint32_t len = end_address - start_address;
			if (len > sizeof(flash_buffer)) len = sizeof(flash_buffer);

			outportw(IO_BANK_2003_RAM, 0);
			memcpy(flash_buffer, UNPACK_BUFFER + i, len);
			if (!nile_mcu_boot_write_memory(start_address, flash_buffer, len)) {
				updater_flash_error();
			}
			if (!nile_mcu_boot_read_memory(start_address, verify_buffer, len)) {
				updater_flash_error();
			}

			outportw(IO_BANK_2003_RAM, 0);
			if (memcmp(verify_buffer, UNPACK_BUFFER + i, len)) {
				updater_flash_error();
			}

			start_address += len;
			i += len;
		}
	}

	console_print_status(true);
	console_print_newline();
}

void run_update_manifest(bool verify) {
	uint8_t *cmd_ptr = update_manifest_data;
	cmd_ptr += sizeof(um_header_t);

	update_verify = verify;
	update_part = 0;

	while (*cmd_ptr) {
		++update_part;

		switch (*cmd_ptr) {
			case UM_CMD_END:
				return;
			case UM_CMD_FLASH:
			case UM_CMD_PACKED_FLASH:
			{
				um_flash_cmd_t *cmd = (um_flash_cmd_t*) cmd_ptr;
				cmd_ptr += sizeof(um_flash_cmd_t);
				run_um_cmd_flash(cmd);
			} break;
			case UM_CMD_MCU_FLASH:
			case UM_CMD_MCU_PACKED_FLASH:
			{
				um_flash_cmd_t *cmd = (um_flash_cmd_t*) cmd_ptr;
				cmd_ptr += sizeof(um_flash_cmd_t);
				run_um_cmd_mcu_flash(cmd);
			} break;
			default:
				updater_early_error(s_corrupt_data, *cmd_ptr);
				break;
		}
	}
}

static uint32_t supported_flash_chips[] = {
	NILE_FLASH_ID_W25Q16JV_IQ,
	NILE_FLASH_ID_W25Q16JV_IM
};
#define SUPPORTED_FLASH_CHIPS_COUNT (sizeof(supported_flash_chips) / sizeof(uint32_t))
static bool flash_chip_supported(void) {
	for (int i = 0; i < SUPPORTED_FLASH_CHIPS_COUNT; i++)
		if (supported_flash_chips[i] == flash_id)
			return true;
	return false;
}

static const char __far version_template[] = "%d.%d.%d (%08lx)";
static void print_version(um_version_t __far* version) {
	console_printf(0, version_template, version->major, version->minor, version->patch,
		__builtin_bswap32(*((uint32_t*) version->commit_id)));
}

__attribute__((interrupt, assume_ss_data))
void __far low_battery_nmi_handler(void) {
	console_clear();
	if (ws_system_color_active()) {
		MEM_COLOR_PALETTE(0)[0] = 0x0F00;
		MEM_COLOR_PALETTE(0)[1] = 0x0FFF;
	} else {
		outportw(IO_SCR_PAL(0), MONO_PAL_COLORS(7, 0, 2, 5));
	}
	console_draw(0, 7, CONSOLE_FLAG_CENTER, s_low_battery);
	while(1);
}

void main(void) {
	cpu_irq_disable();
	ws_hwint_set_handler(HWINT_IDX_VBLANK, vblank_int_handler);
	ws_hwint_enable(HWINT_VBLANK);
	cpu_irq_enable();

	console_init();

	console_draw_header(s_update_title);
	console_print(0, s_initializing_updater);

	nile_io_unlock();
	nile_bank_unlock();

	nile_flash_wake();

	flash_id = nile_flash_read_id();
	if (!flash_chip_supported()) {
		console_print_status(false);
		console_print_newline();
		console_printf(0, s_unknown_flash_error, flash_id);
		while(1);
	}

	nile_flash_write_unlock_global();

	// == LOW BATTERY NMI ENABLED ==
	ws_cpuint_set_handler(CPUINT_IDX_NMI, low_battery_nmi_handler);
	outportb(IO_INT_NMI_CTRL, NMI_ON_LOW_BATTERY);	

	// Copy and validate update manifest
	uint16_t update_manifest_seg = (*((uint8_t __far*) MK_FP(0xF000, 0xFFF6))) << 8;
	uint16_t __far* update_manifest_start = MK_FP(update_manifest_seg, 0);
	if (update_manifest_start[0] > sizeof(update_manifest_data))
		updater_early_error(s_corrupt_data, update_manifest_seg);
	memset(update_manifest_data, 0, sizeof(update_manifest_data));
	memcpy(update_manifest_data, update_manifest_start + 2, update_manifest_start[0]);
	uint16_t actual_crc16 = crc16((const char*) update_manifest_data, update_manifest_start[0], 0);
	if (actual_crc16 != update_manifest_start[1])
		updater_early_error(s_corrupt_data, actual_crc16);

	console_print_status(true);
	console_print_newline();
	run_update_manifest(true);

	// Display update screen
	console_print_newline();
	console_print(CONSOLE_FLAG_MONOSPACE, s_nileswan_header);
	console_print(0, s_update_title);
	console_print_newline();
	console_print(0, s_update_version);
	print_version(&((um_header_t*) update_manifest_data)->version);
	console_print_newline();
	console_print_newline();
	console_print(0, s_update_disclaimer);
	console_print_newline();
	
	input_wait_key(KEY_A);
	
	outportb(IO_INT_NMI_CTRL, 0);
	// == LOW BATTERY NMI DISABLED ==

	console_print_newline();
	run_update_manifest(false);
	
	nile_flash_sleep();
	outportb(IO_NILE_POW_CNT, 0);

	console_print_newline();
	console_print(0, s_update_success);
	if (ws_system_is_color()) {
		console_print(0, s_press_a_shutdown);
		console_print_newline();
		input_wait_key(KEY_A);
		outportb(IO_SYSTEM_CTRL3, SYSTEM_CTRL3_POWEROFF);
	} else {
		console_print(0, s_manual_shutdown);
		console_print_newline();
	}

	update_halt();
}

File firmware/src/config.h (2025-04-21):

/**
 * Copyright (c) 2024 Adrian Siekierka
 *
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
 * You should have received a copy of the GNU General Public License along
 * with Nileswan MCU. If not, see <https://www.gnu.org/licenses/>.
 */

#ifndef _CONFIG_H_
#define _CONFIG_H_

// Feature flags

// Enable full EEPROM emulation.
// If disabled, READ and WDS/WEN commands are ignored (emulated on FPGA side only).
// #define CONFIG_FULL_EEPROM_EMULATION

#define CONFIG_ENABLE_CDC_DEBUG_PORT

// Firmware configuration

#define MCU_SPI_MAX_PACKET_SIZE 512
#define MCU_SPI_RX_BUFFER_SIZE (MCU_SPI_MAX_PACKET_SIZE)
#define MCU_SPI_TX_BUFFER_SIZE ((MCU_SPI_MAX_PACKET_SIZE) + 2)

// MCU configuration

#define MCU_UID_LENGTH 12

// Debug configuration

#define CONFIG_DEBUG_SPI_NATIVE_CMD
// #define CONFIG_DEBUG_SPI_EEPROM_CMD
// #define CONFIG_DEBUG_SPI_RTC_CMD
// #define CONFIG_DEBUG_SPI_DISABLE_PROCESSING

// GPIO A
#define MCU_PORT_SPI GPIOA
#define MCU_PIN_FPGA_BUSY LL_GPIO_PIN_1
#define MCU_PIN_FPGA_IRQ LL_GPIO_PIN_3
#define MCU_PIN_SPI_NSS LL_GPIO_PIN_4
#define MCU_PIN_SPI_SCK LL_GPIO_PIN_5
#define MCU_PIN_SPI_POCI LL_GPIO_PIN_6
#define MCU_PIN_SPI_PICO LL_GPIO_PIN_7
#define MCU_PERIPH_SPI SPI1

// GPIO B
#define MCU_PIN_BAT LL_GPIO_PIN_0
#define MCU_PIN_USB_POWER LL_GPIO_PIN_5
#define MCU_PIN_RUNS_ON_BAT LL_GPIO_PIN_7

#define MCU_DMA_CHANNEL_SPI_RX LL_DMA_CHANNEL_2
#define MCU_DMA_CHANNEL_SPI_TX LL_DMA_CHANNEL_3

#define MCU_SPI_FREQ_384KHZ 0
#define MCU_SPI_FREQ_6MHZ   1
#define MCU_SPI_FREQ_24MHZ  2

#define SAVE_ID_NONE 0xFFFFFFFF

#endif /* _CONFIG_H_ */

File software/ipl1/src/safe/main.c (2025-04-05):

/**
 * Copyright (c) 2024 Adrian Siekierka
 *
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
 * You should have received a copy of the GNU General Public License along
 * with Nileswan IPL1. If not, see <https://www.gnu.org/licenses/>.
 */

#include <stddef.h>
#include <string.h>
#include <ws.h>
#include <nile.h>
#include <wsx/zx0.h>
#include "assets/tiles.h"
#include "ipc.h"
#include "util.h"

typedef enum {
	MENU_OPTION_QUICK_TEST_16MB,
	MENU_OPTION_QUICK_TEST_8MB,
	MENU_OPTION_MEMORY_TEST,
	MENU_OPTION_BOOT_RECOVERY_CURRENT,
	MENU_OPTION_BOOT_RECOVERY_FACTORY,
	MENU_OPTION_MANUFACTURING_TEST,
	MENU_OPTION_RETENTION,
	MENU_OPTION_SRAM_SPEED,
	MENU_OPTIONS_COUNT
} menu_option_t;

#define SCREEN ((uint16_t*) (0x3800 + (13 * 32 * 2)))

#define PSRAM_MAX_BANK_8MB 127
#define PSRAM_MAX_BANK_16MB 255
#define PSRAM_MAX_BANK PSRAM_MAX_BANK_8MB
#define SRAM_MAX_BANK 7

/* === Test code in external files === */

// tests_asm.s
extern void ram_fault_test(void *results, uint16_t bank_count);
#define TEST_MODE_DEFAULT 0
#define TEST_MODE_ONLY_READ 1
#define TEST_MODE_BOOL_PASS 254
#define TEST_MODE_BOOL_FAIL 255
extern uint8_t ram_fault_test_mode;
bool ram_fault_test_bool(uint16_t bank_count) {
	ram_fault_test_mode = TEST_MODE_BOOL_PASS;
	ram_fault_test(NULL, bank_count);
	bool result = ram_fault_test_mode == TEST_MODE_BOOL_PASS;
	ram_fault_test_mode = TEST_MODE_DEFAULT;
	return result;
}

/* === Utility functions === */

static void clear_screen(void) {
	ws_screen_fill_tiles(SCREEN, 0x120, 0, 0, 28, 18);
}

#define DRAW_STRING(x, y, s, pal) mem_expand_8_16(SCREEN + ((y) * 32) + (x), (s), sizeof(s) - 1, 0x100 | pal);
#define DRAW_STRING_CENTERED(y, s, pal) DRAW_STRING(((29 - sizeof(s)) >> 1), y, s, pal)
#define DRAW_STRING_DYNAMIC(x, y, s, pal) mem_expand_8_16(SCREEN + ((y) * 32) + (x), (s), strlen(s), 0x100 | pal);
#define DRAW_STRING_CENTERED_DYNAMIC(y, s, pal) DRAW_STRING_DYNAMIC(((30 - strlen(s)) >> 1), y, s, pal)

/* === Memory test === */

static void draw_pass_fail(uint8_t y, bool result) {
	mem_expand_8_16(SCREEN + ((y * 32)) + 22, result ? "PASS" : "FAIL", 4, SCR_ENTRY_PALETTE(result ? 3 : 2) | 0x100);
}

static void draw_result_byte(uint8_t y, uint8_t value, bool result) {
	uint16_t* dst = SCREEN + ((y * 32)) + 22;
	if (result)
		print_hex_number(dst, value);
	else
		mem_expand_8_16(dst, "FAIL", 4, SCR_ENTRY_PALETTE(result ? 3 : 2) | 0x100);
}

static void wait_for_button(void) {
	DRAW_STRING_CENTERED(17, "press any button", 0);
	while(!ws_keypad_scan());
	while(ws_keypad_scan());
}

static bool ipc_buf_test() {
	outportw(IO_BANK_2003_RAM, 14);
	__far uint16_t* ipc_buf = MK_FP(0x1000, 0);

	for (uint16_t i = 0; i < sizeof(nile_ipc_t); i+=2)
		*(ipc_buf++) = i ^ (i >> 8);

	// IPC buffer should mirror
	for (uint16_t i = 0; i < sizeof(nile_ipc_t); i+=2)
	{
		if (*(ipc_buf++) != (i ^ (i >> 8)))
			return false;
	}

	return true;
}

void run_quick_test(int psram_max_bank) {
	clear_screen();
	DRAW_STRING_CENTERED(0, "quick test in progress", 0);

	DRAW_STRING(2, 2, "PSRAM write/read", 0);
	outportb(IO_CART_FLASH, 1);
	draw_pass_fail(2, ram_fault_test_bool(psram_max_bank));
	DRAW_STRING(2, 3, "SRAM write/read", 0);
	outportb(IO_CART_FLASH, 0);
	draw_pass_fail(3, ram_fault_test_bool(SRAM_MAX_BANK + 1));

	DRAW_STRING(2, 4, "IPC buf write/read", 0);
	draw_pass_fail(4, ipc_buf_test());

	ws_screen_fill_tiles(SCREEN, 0x120, 0, 0, 28, 1);
	DRAW_STRING_CENTERED(0, "quick test complete", 0);
	wait_for_button();
}

void run_full_memory_test(bool loop) {
	clear_screen();
	DRAW_STRING(3, 0, "PSRAM  Mem. Test  SRAM", 0);

	do {
		outportb(IO_CART_FLASH, 1);
		ram_fault_test(SCREEN + (1 * 32), PSRAM_MAX_BANK_16MB + 1);
		outportb(IO_CART_FLASH, 0);
		ram_fault_test(SCREEN + (1 * 32) + 19, SRAM_MAX_BANK + 1);
	} while(loop);
}

void run_read_memory_test(void) {
	clear_screen();
	DRAW_STRING_CENTERED(0, "testing SRAM read", 0);
	DRAW_STRING(19, 2, "76543210", 0);

	while (true) {
		outportb(IO_CART_FLASH, 0);
		ram_fault_test_mode = TEST_MODE_ONLY_READ;
		ram_fault_test(SCREEN + (3 * 32) + 19, SRAM_MAX_BANK + 1);
		ram_fault_test_mode = TEST_MODE_DEFAULT;
	}
	wait_for_button();
}

bool load_spi_flash(uint32_t _offset, uint16_t banks) {
	uint8_t buffer[256];
	uint32_t offset;

	outportb(IO_CART_FLASH, 1);
	nile_flash_wake();

	offset = _offset;
	// Quickly load all data from SPI flash to PSRAM
	DRAW_STRING(1, 1, "writing bank ", 0);
	for (uint16_t bank = PSRAM_MAX_BANK + 1 - banks; bank <= PSRAM_MAX_BANK; bank++) {
		outportw(IO_BANK_2003_RAM, bank);
		print_hex_number(SCREEN + (1 * 32) + 14, bank);

		for (int i = 0; i < 2; i++) {
			if (!nile_flash_read(MK_FP(0x1000, i << 15), offset, 0x8000)) {
				DRAW_STRING(1, 2, "flash read error", 0);
				print_hex_number(SCREEN + (3 * 32) + 1, offset >> 16);
				print_hex_number(SCREEN + (3 * 32) + 5, offset);
				return false;
			}
			offset += 0x8000;
		}
	}

	offset = _offset;
	// Verify data was loaded correctly (in case PSRAM is damaged)
	DRAW_STRING(1, 2, "verifying bank ", 0);
	for (uint16_t bank = PSRAM_MAX_BANK + 1 - banks; bank <= PSRAM_MAX_BANK; bank++) {
		outportw(IO_BANK_2003_RAM, bank);
		print_hex_number(SCREEN + (2 * 32) + 16, bank);

		for (int i = 0; i < (65536 / sizeof(buffer)); i++) {
			if (!nile_flash_read(buffer, offset, sizeof(buffer))) {
				DRAW_STRING(1, 3, "flash read error", 0);
				print_hex_number(SCREEN + (4 * 32) + 1, offset >> 16);
				print_hex_number(SCREEN + (4 * 32) + 5, offset);
				return false;
			}
			if (memcmp(MK_FP(0x1000, i * sizeof(buffer)), buffer, sizeof(buffer))) {
				DRAW_STRING(1, 3, "PSRAM write error", 0);
				print_hex_number(SCREEN + (4 * 32) + 1, offset >> 16);
				print_hex_number(SCREEN + (4 * 32) + 5, offset);
				return false;
			}
			offset += sizeof(buffer);
		}
	}

	return true;
}

void try_boot_rom(void) {
	outportb(IO_CART_FLASH, 0);
	outportw(IO_BANK_2003_ROM0, PSRAM_MAX_BANK);
	outportw(IO_BANK_2003_ROM1, PSRAM_MAX_BANK - 12);
	outportw(IO_BANK_2003_RAM, 0);
	outportw(IO_BANK_ROM_LINEAR, PSRAM_MAX_BANK >> 4);

	uint8_t __far* header = MK_FP(0xFFFF, 0x0000);
	if (header[0] != 0xEA) return;

	outportb(IO_DISPLAY_CTRL, 0);
	outportb(IO_SCR1_SCRL_Y, 0);
	asm volatile("ljmp $0x2FFF, $0x0000");
}
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

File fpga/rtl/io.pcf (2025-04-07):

set_io FastClk 34
set_io FastClkEnable 1

set_io -pullup yes Button 51

set_io AddrLo[0] 69
set_io AddrLo[1] 71
set_io AddrLo[2] 72
set_io AddrLo[3] 73
set_io AddrLo[4] 59
set_io AddrLo[5] 60
set_io AddrLo[6] 64
set_io AddrLo[7] 65
set_io AddrLo[8] 66
set_io AddrLo[9] 68

set_io AddrHi[0] 18
set_io AddrHi[1] 19
set_io AddrHi[2] 20
set_io AddrHi[3] 21

set_io Data[0] 78
set_io Data[1] 79
set_io Data[2] 80
set_io Data[3] 81
set_io Data[4] 82
set_io Data[5] 85
set_io Data[6] 83
set_io Data[7] 86
set_io Data[8] 24
set_io Data[9] 25
set_io Data[10] 26
set_io Data[11] 27
set_io Data[12] 93
set_io Data[13] 95
set_io Data[14] 94
set_io Data[15] 96

set_io MBC 12
set_io SClk 33

set_io nOE 13
set_io nWE 15
set_io nSel 9
set_io nIO 10

set_io nMem_OE 28
set_io nMem_WE 87

set_io nCartInt 8

set_io nPSRAM1Sel 30
set_io nPSRAM2Sel 36
set_io PSRAM_nUB 52
set_io PSRAM_nLB 29
set_io PSRAM_nZZ 16

set_io nSRAMSel 74

set_io AddrExt[0] 42
set_io AddrExt[1] 40
set_io AddrExt[2] 37
set_io AddrExt[3] 100
set_io AddrExt[4] 99
set_io AddrExt[5] 97
set_io AddrExt[6] 41

set_io nMCUSel 56
set_io nFlashSel 49
set_io SPIClk 48
set_io SPIDo 45
set_io -pullup yes SPIDi 46

set_io nMCUReset 54
set_io MCUReady 57
set_io nMCUInt 53

set_io nTFSel 7
set_io TFDo 4
set_io TFDi 2
set_io TFClk 3

set_io TFPow 91

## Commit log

2023-08-23 first prototype of the PCB
    [AMPMAMPM_2.0 x 1.6 mm.step, IS66WVE4M16EBLL-70BLI.STEP, W25Q16JVZPIQ.STEP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]
2023-09-28 current erata, ibom and PCB changes necessary to manufacture it
    [nileswan.kicad_pcb]
2023-12-27 initial progress on firmware/fpga side
    [fpga.kicad_sch]
2023-12-28 improve makefile, gitignore, fix build
    [nileswan.sv]
2024-01-29 clarify SPI transfer length
2024-02-07 second pcb iteration
    [DM3AT-SF-PEJM5--3DModel-STEP-418109.STEP, SM02B-SRSS-TB_LF__SN_.step, TPS3619-50DGK.step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]
2024-02-07 fpga/ipl0, ipl1: new implementation
    Rewritten from scratch.
    - Compliant with the current (as of writing) programming environment
    specification.
    - IPL1 now supports running a simple self-test (hold X3+A on boot).
    - IPL1 now loads a "menu.ws" file from the root of the SD card.
2024-02-08 ipl1: add readable error messages, fix selftest
    [main.c]
2024-02-08 ipl1: add SPI timeout handling
2024-02-09 ipl1: card driver, logging improvements
2024-02-10 ipl1: deinitialize hardware on failure to save power
    [main.c]
2024-02-10 first bit errata for new pcb iteration
2024-02-10 adapt gateware to pcb changes, new SPI interface and refactoring
2024-02-11 ipl1: power off card on initialization failure, cleanup init code
2024-02-12 implement second SPI channel and a few fixes
    [io.pcf, nileswan.sv, spi.sv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]
2024-02-14 ipl1: all the fixes required to boot on hardware
    [main.c]
2024-02-14 ipl1: selftest: basic menu framework, quick test/io speed control options
2024-02-14 improve SPI bench
2024-04-02 pcb revision 3 and 16 MB PSRAM support
    [74LVC245ABQ.step, BAT-HLD-012-SMT.step, SIT8021AI-J4-XXS-24.000000E.step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]
2024-04-27 Document link on PCB silkscreen being wrong
2024-04-27 WIP shell
    [shell.FCStd]
2024-04-27 use correct footprint for R12
    [nileswan.kicad_sch]
2024-05-01 implement new combined SPI cs/device select also make signal naming a bit more consistent
2024-05-04 move simulated SPI device into a macro
2024-05-04 document another PCB mistake
2024-06-07 MCU firmware flashing and basic SPI communication
2024-08-05 implement mcu reset in POW_CNT
    [io.pcf, main.c, nileswan.sv]
2024-08-11 ipl0, ipl1: move to libnile over bundled code, fixes/tweaks, add updater tool
    [main.c]
2024-08-11 ipl0: fix cancelling spi read
2024-08-11 ipl1: push MCU SPI serial port testing code
2024-08-11 ipl1: selftest MCU fixes
    [main.c]
2024-11-24 FPGA side mcu boot0 workaround for pcb rev4 where boot0 is connected to POCI instead of PICO
    [nileswan.sv, spi.sv]
2024-11-26 ipl1: update libnile, fix typo
    [main.c]
2024-12-16 ipl1, libnile: fix IPC initialization
    [main.c]
2024-12-17 firmware: fix race condition on startup
    [spi.c]
2025-01-01 docs, manifest, ipl0: adjust SPI flash layout
2025-01-02 EEPROM SPI output and RTC
2025-01-06 make anti output glitch part actually work
    [nileswan.sv]
2025-01-06 firmware: start working on STM32U0 build
2025-02-21 implement SPI transfer stopping
2025-03-11 remove X state, yosys doesn't seem to like it
    [eeprom.sv, rtc.sv]
2025-03-11 SPI transaction stop test
2025-03-11 U0 mcu firmware code fixes
    [config.h, mcu.c, spi.c]
2025-03-11 fix U0 USB hot plugging for good
    [mcu.c]
2025-03-12 make μC busy/BOOT0 line open drain
2025-03-15 fix FPGA side RTC emulation
    [rtc.sv]
2025-03-16 nit: fix RTC command enum order
    [rtc.sv]
2025-03-22 ipl1: add way to boot IPL1 from BootFriend in case of an IPL1 brick
2025-03-23 firmware: switch from HSI16 to MSI
2025-03-29 firmware: fix MSI clock, add USB shutoff, reclocking
    [config.h, mcu.c, spi.c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]
2025-03-29 firmware: fix MCU_PIN_BAT detection
    [mcu.c]
2025-03-29 firmware: spi: deinit/init improvements
2025-03-29 updater: fix poweroff
2025-03-29 fix RTC FPGA - the enum seems to not work with yosys - fix length of undefined commands - unset busy bit together with ready bit
    [rtc.sv]
2025-03-30 fix transfering received data to RTC data register
    [rtc.sv]
2025-03-30 rtc, spi: fix rtc reset, minor cleanup
    [config.h, spi.c]
2025-03-30 rtc, spi: fixes
2025-03-30 firmware: spi: use DMA for 0xFF response padding in native mode
2025-03-30 firmware: mcu, spi: busy bit tweaks, voltage regulation
2025-03-31 updater: allow <1MB images, stability improvements
    [main.c]
2025-04-01 recovery, updater: rework directory layout to allow for shared code
    [main.c]
2025-04-02 ipl1, recovery: implement manufacturing test flow
2025-04-02 ipl1: additional logging on crash
    [main.c]
2025-04-04 implement boot splash bypass when button is pressed
2025-04-05 ipl1: fix IPC restore on warmboot
    [main.c]
2025-04-05 ipl1: fix null pointer write
    [main.c]
2025-04-06 make RTC work (hopefully) - redo part of the state machine - make command start clear the ready bit - (workaround?) delay ack signal by 64 cycles, then everything starts to work
    [nileswan.sv, rtc.sv]
2025-04-06 fpga: code review fixes
    [nileswan.sv]
2025-04-06 remove RTC workaround of adding extra cycles until ack is used
    [rtc.sv]
2025-04-06 firmware: spi: fix first byte transmitted after mode switch being 0xFF
    [spi.c]
2025-04-06 recovery: add RTC stability test
    [main.c]
2025-04-07 fix register enable_rom_8bit_bus register definition
    [nileswan.sv]
2025-04-07 remove old boot0 via SPI Di workaround
    [nileswan.sv, spi.sv]
2025-04-07 add /MCUInt to FPGA pin definitions
2025-04-08 firmware: initial RTC interrupt implementation (mostly correct, somewhat inefficient)
    [spi.c]
2025-04-09 ipl0, ipl1: reset/preserve more sytsem state
    [main.c]
2025-04-11 recovery: add soft reset
    [main.c]
2025-04-12 fpga, ipl0, libnile, docs: swap port 0xE3 and 0xE6
    [nileswan.sv]
2025-04-13 docs, fpga: add BOARD_REVISION
2025-04-15 firmware: avoid SRAM2 retention when unnecessary
    [config.h, mcu.c, spi_cmd.c]
2025-04-20 libnile, updater: add per-board-revision updates
2025-04-26 firmware: clock CPU faster in 6MHz SPI mode

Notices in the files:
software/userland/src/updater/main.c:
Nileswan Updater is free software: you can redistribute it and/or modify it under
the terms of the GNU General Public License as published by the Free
